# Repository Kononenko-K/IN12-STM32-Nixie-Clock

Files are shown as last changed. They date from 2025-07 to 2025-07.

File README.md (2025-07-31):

# IN12-STM32-Nixie-Clock

STM32 Nixie clock project with four Soviet IN-12 indicators.

<br/>
<p align="center">
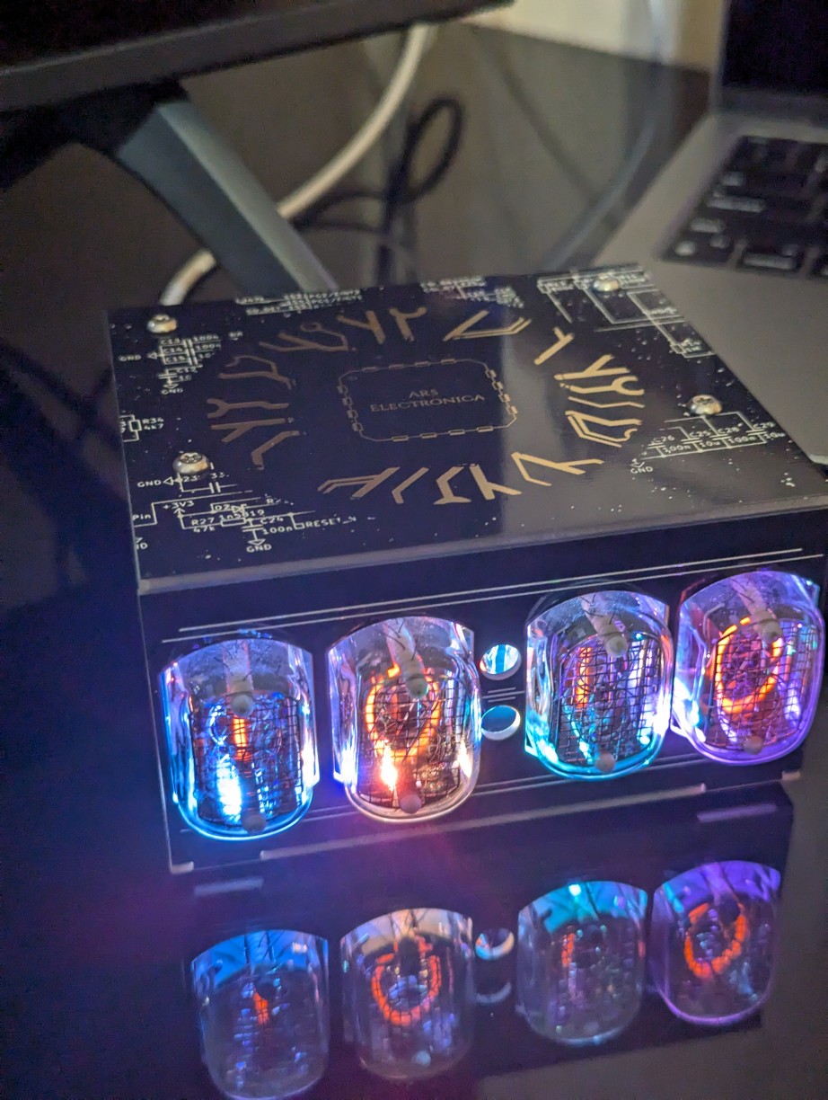
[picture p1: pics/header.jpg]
    
</p>

## Overview

<br/>
<p align="center">
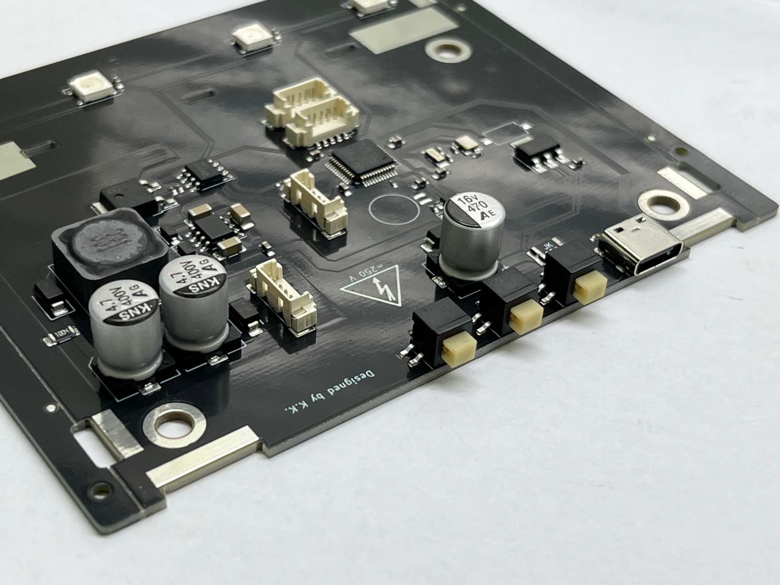
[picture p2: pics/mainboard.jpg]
    
</p>

This project provides a complete solution for building an STM32-powered 
Nixie clock with Soviet IN-12 tubes. It operates on a 5V power supply 
via a Type-C connector and features an internal high voltage generator.

## Hardware

<br/>
<p align="center">
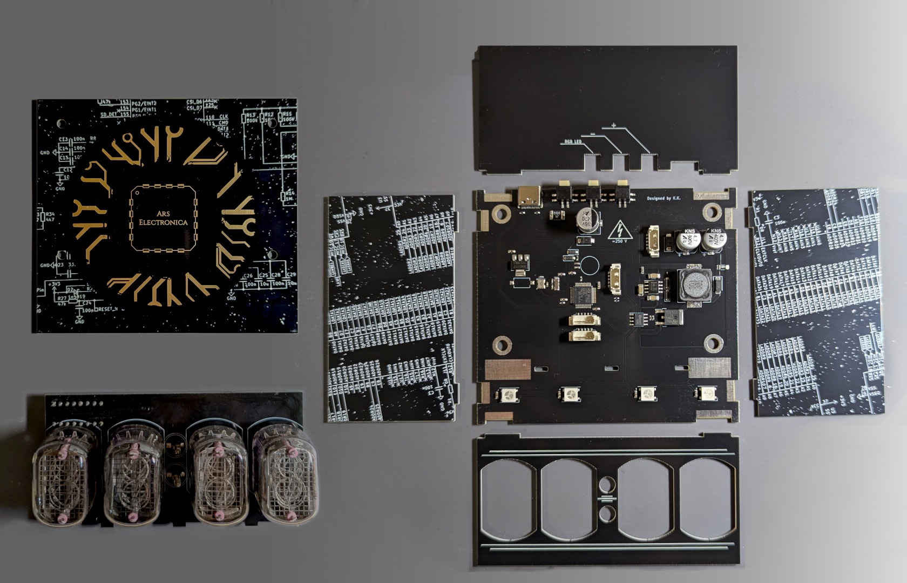
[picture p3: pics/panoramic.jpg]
    
</p>

### [**Display Module**](/Hardware/nixie%20display/project.pdf)
- Utilizes the K155ID1 (equivalent to SN74141N) as a high-voltage 
BCD-to-decimal decoder.
- Drives four Nixie tubes using dynamic scanning with TLP627 optocouplers.

### [**Controller Module**](/Hardware/mcu%20board/project.pdf)
- Based on the STM32F103C8Tx microcontroller, featuring:
  - Internal RTC peripheral for timekeeping;
  - Battery input for maintaining time during power off;
  - Boost converter for high-voltage generation using a PWM signal from 
one of the MCU's timers;
  - Four WS2812B addressable RGB LEDs for tube illumination.

### **Connection Guide**

| **Display Module** | **Controller Module** |
|---|---|
| A1 | PA4 |
| A2 | PA6 |
| A3 | PB0 |
| A4 | PB2 |
|--------------------|-----------------------|
| D0 | PA5 |
| D1 | PB1 |
| D2 | PB10 |
| D3 | PA7 |
|--------------------|-----------------------|
| NE | PA10 |
|--------------------|-----------------------|
| +180V | HV |
|--------------------|-----------------------|
| +5V | +5V |

Connect all respective GNDs together.

## Firmware

The firmware is developed as a Makefile project, generated with 
STM32CubeMX. It can be built using:

```sh
make clean && make
```

To upload the firmware, use ST-LINK/V2 and OpenOCD with the following 
command:

```sh
openocd -f interface/stlink.cfg \
          -f target/stm32f1x.cfg \
          -c "init; reset halt; flash write_image erase ./build/new_nixie.bin 0x08000000; reset halt; exit"
```

The code implements firmware protection and it can be removed with:
```sh
openocd -f interface/stlink.cfg \
          -f target/stm32f1x.cfg \
          -c "init; reset halt; stm32f1x unlock 0; reset halt; exit"
```

For convenience, you can use the provided scripts:
- [flash.sh](/Firmware/flash.sh)
- [remove_protection.sh](/Firmware/remove_protection.sh)

The boost converter's duty cycle may require adjustment based on component 
type. Additionally, delay settings can be fine-tuned for optimal tube 
switching. The firmware includes a feature to prevent cathode poisoning by 
cycling through all tubes every 5 minutes. Also, there are 15 different modes 
of illumination using addressable LEDs.

## License

- The **Firmware** in this project is licensed under the 
[MIT License](/Firmware/LICENSE), with the exception of portions of the 
firmware code that are copyrighted by STMicroelectronics; such portions are 
subject to the original licensing terms provided by STMicroelectronics.
- The **Hardware** in this project is licensed under the 
[CERN Open Hardware Licence Permissive (CERN OHL-P)](/Hardware/LICENSE).

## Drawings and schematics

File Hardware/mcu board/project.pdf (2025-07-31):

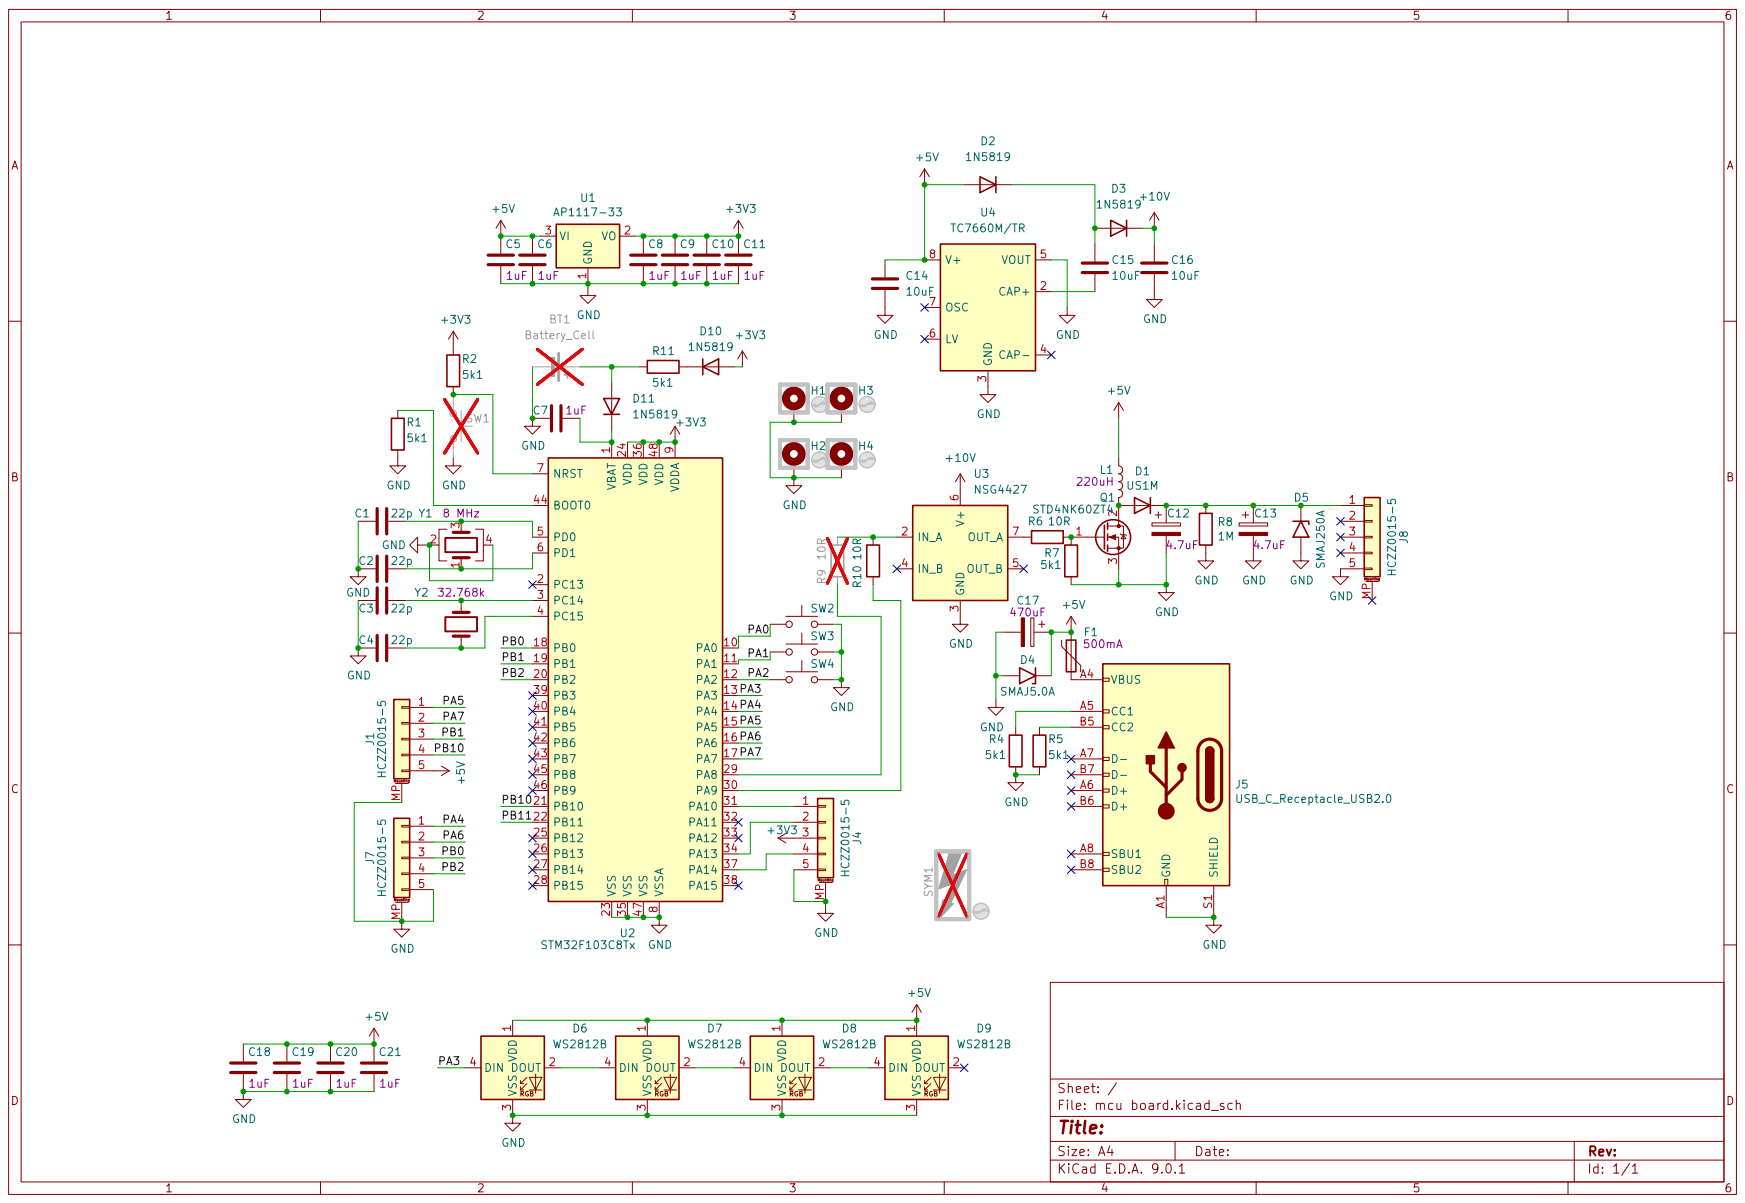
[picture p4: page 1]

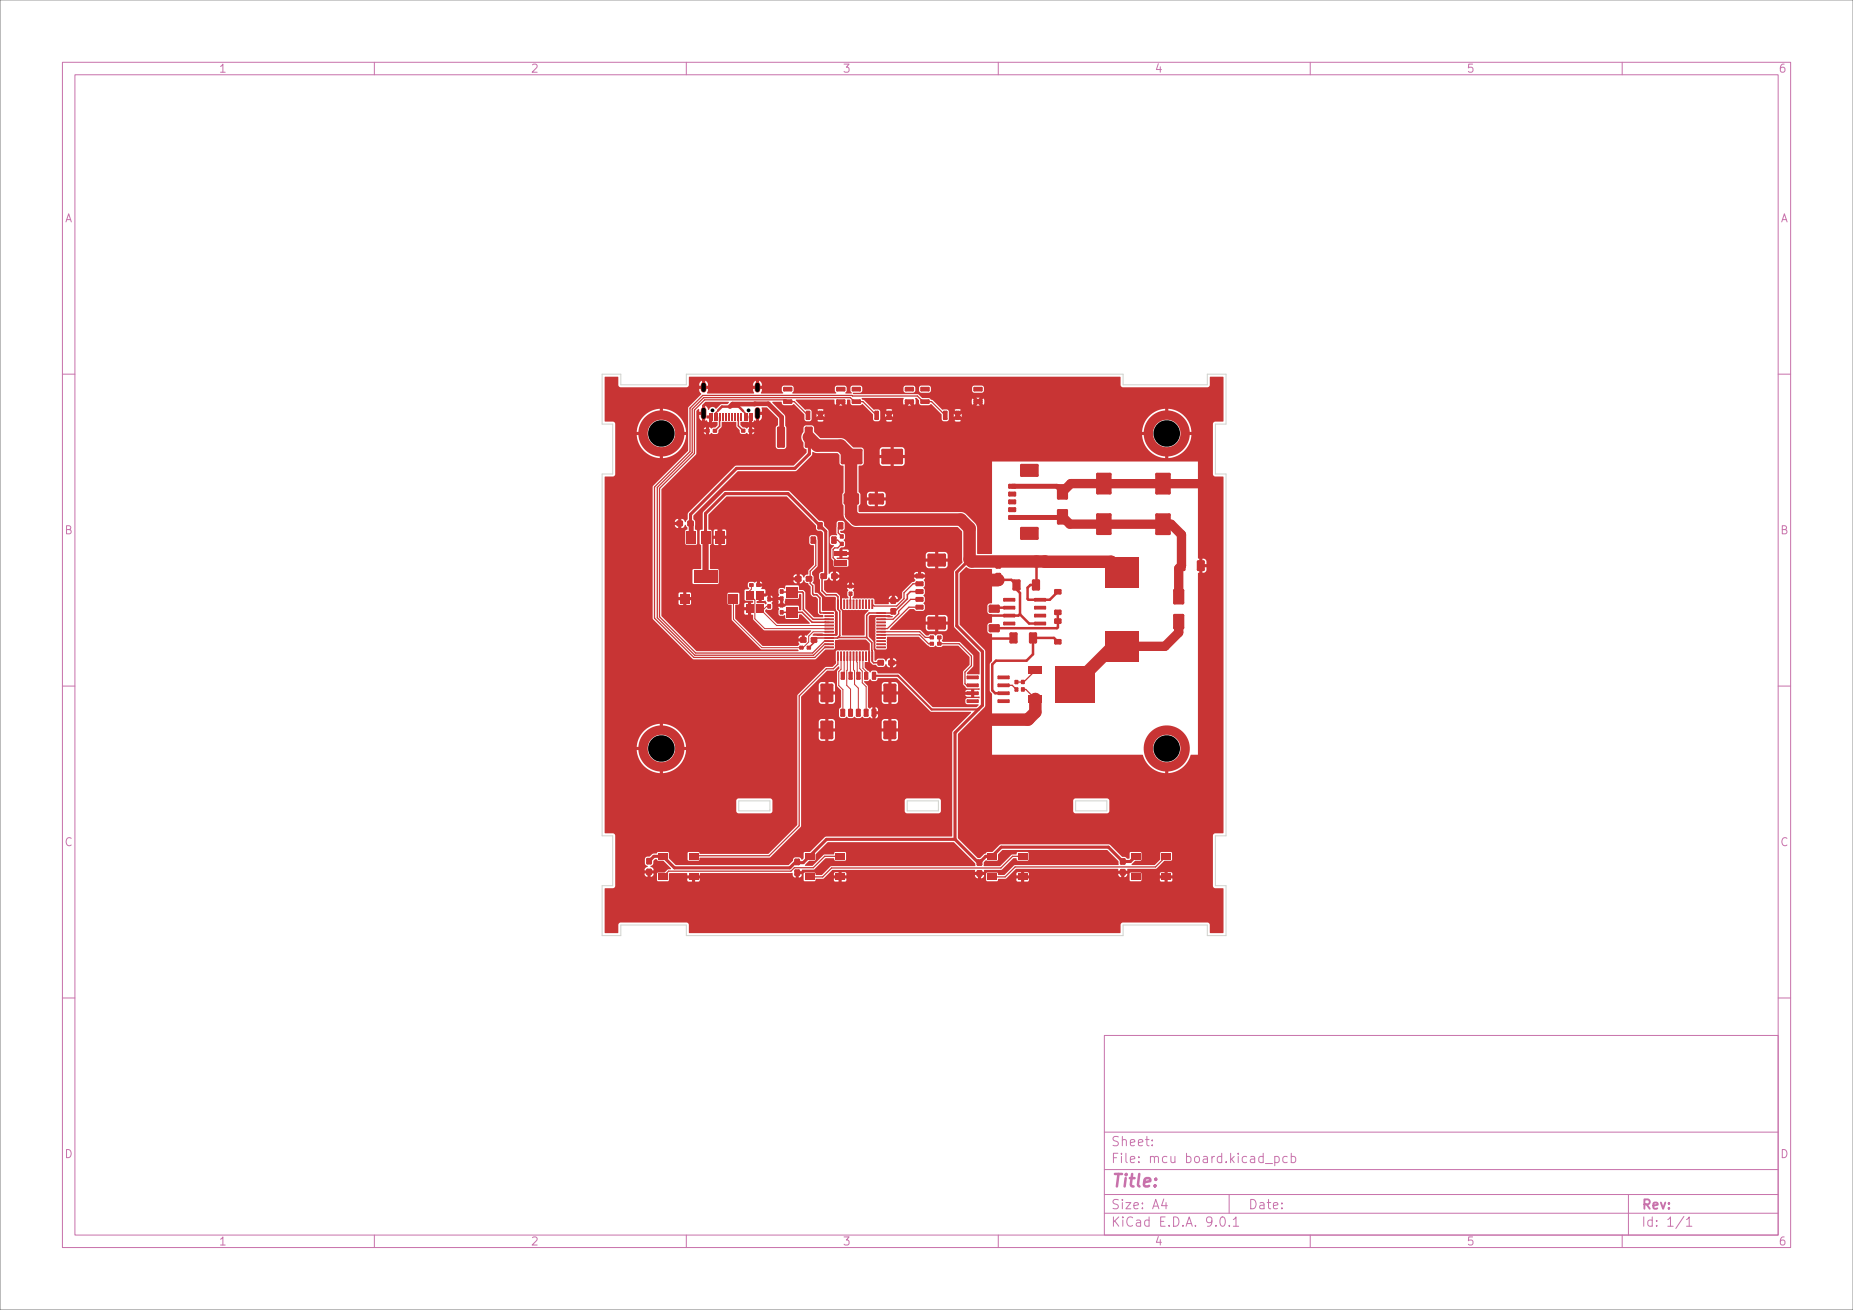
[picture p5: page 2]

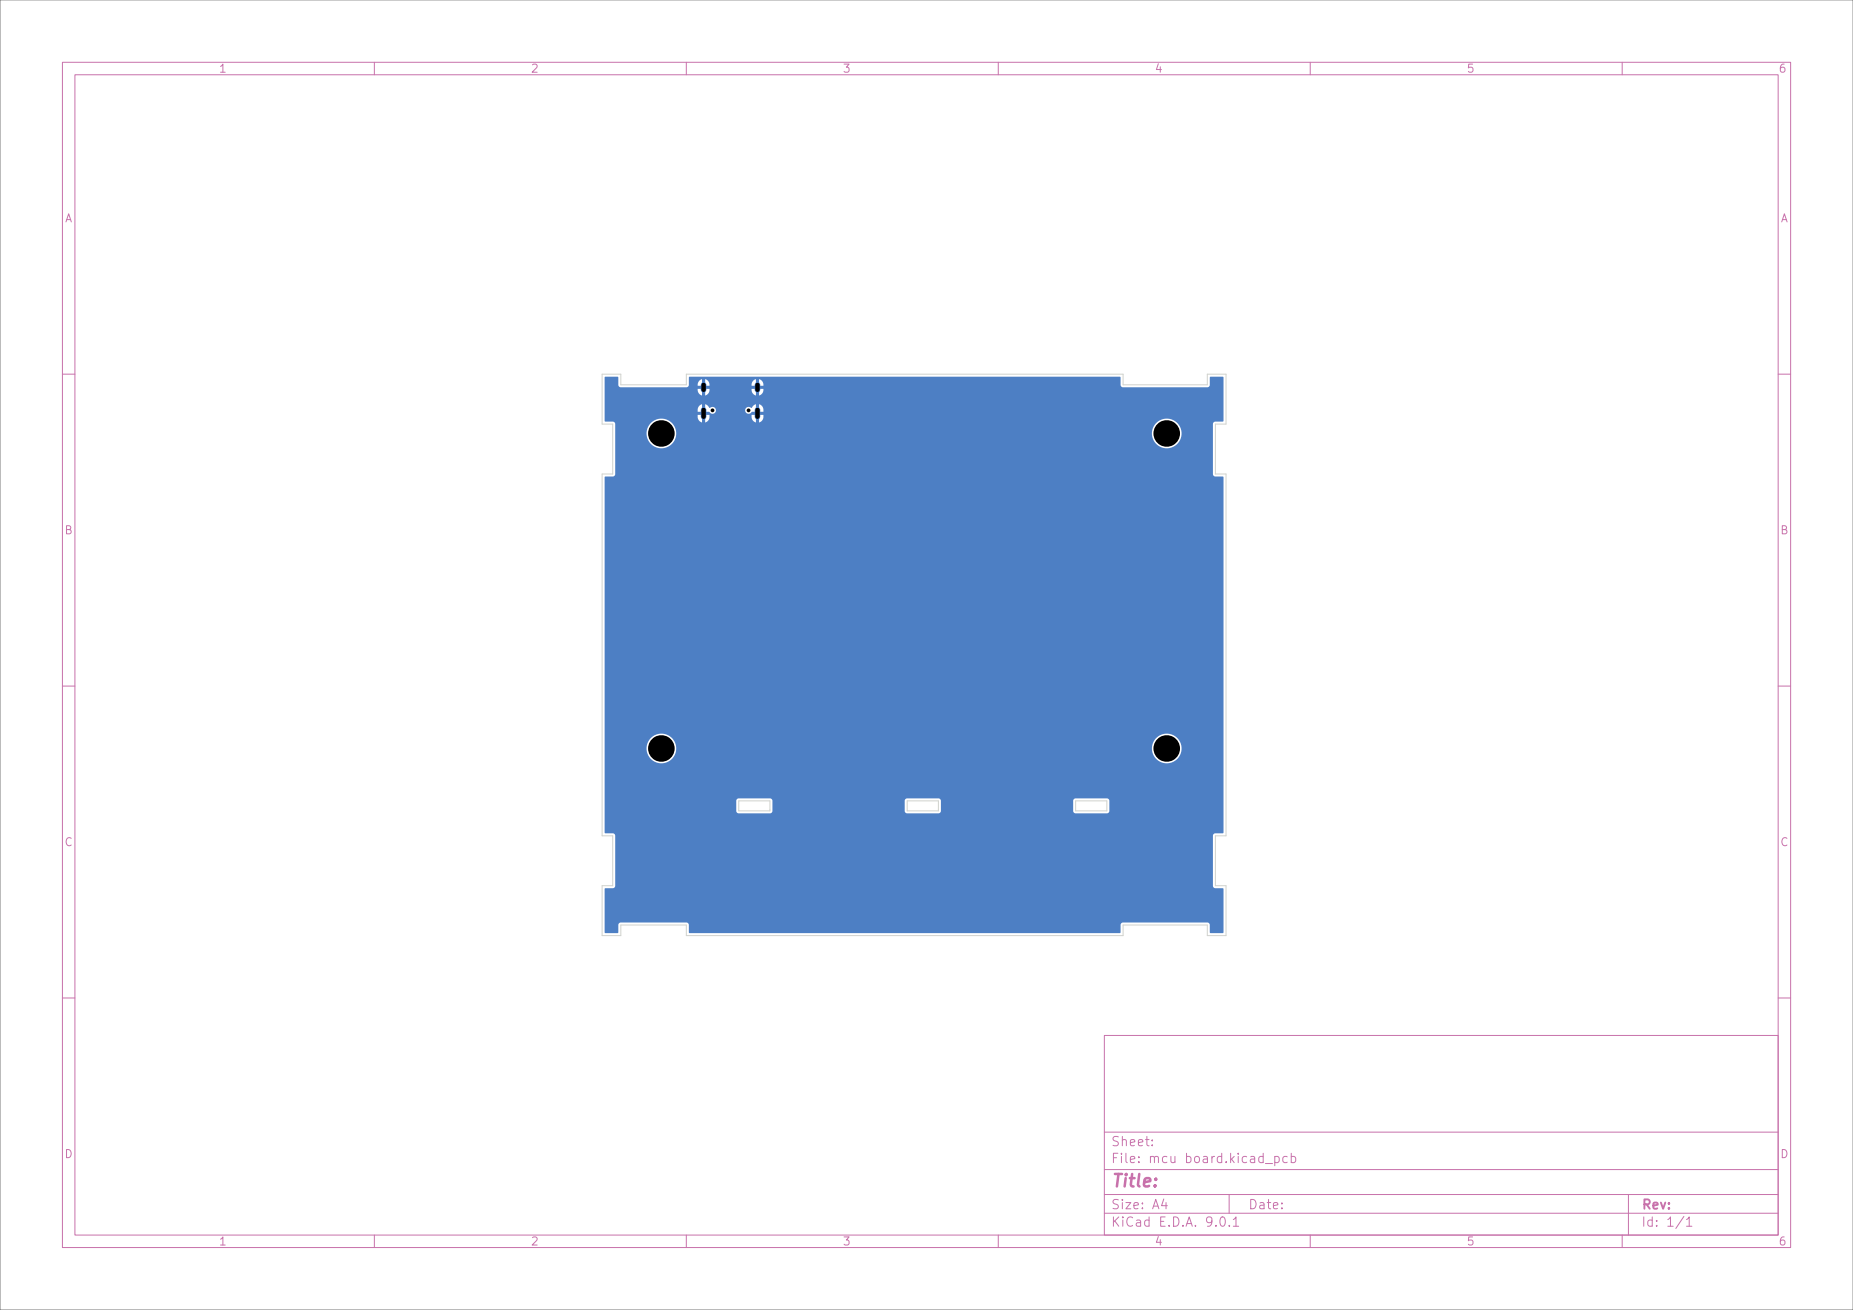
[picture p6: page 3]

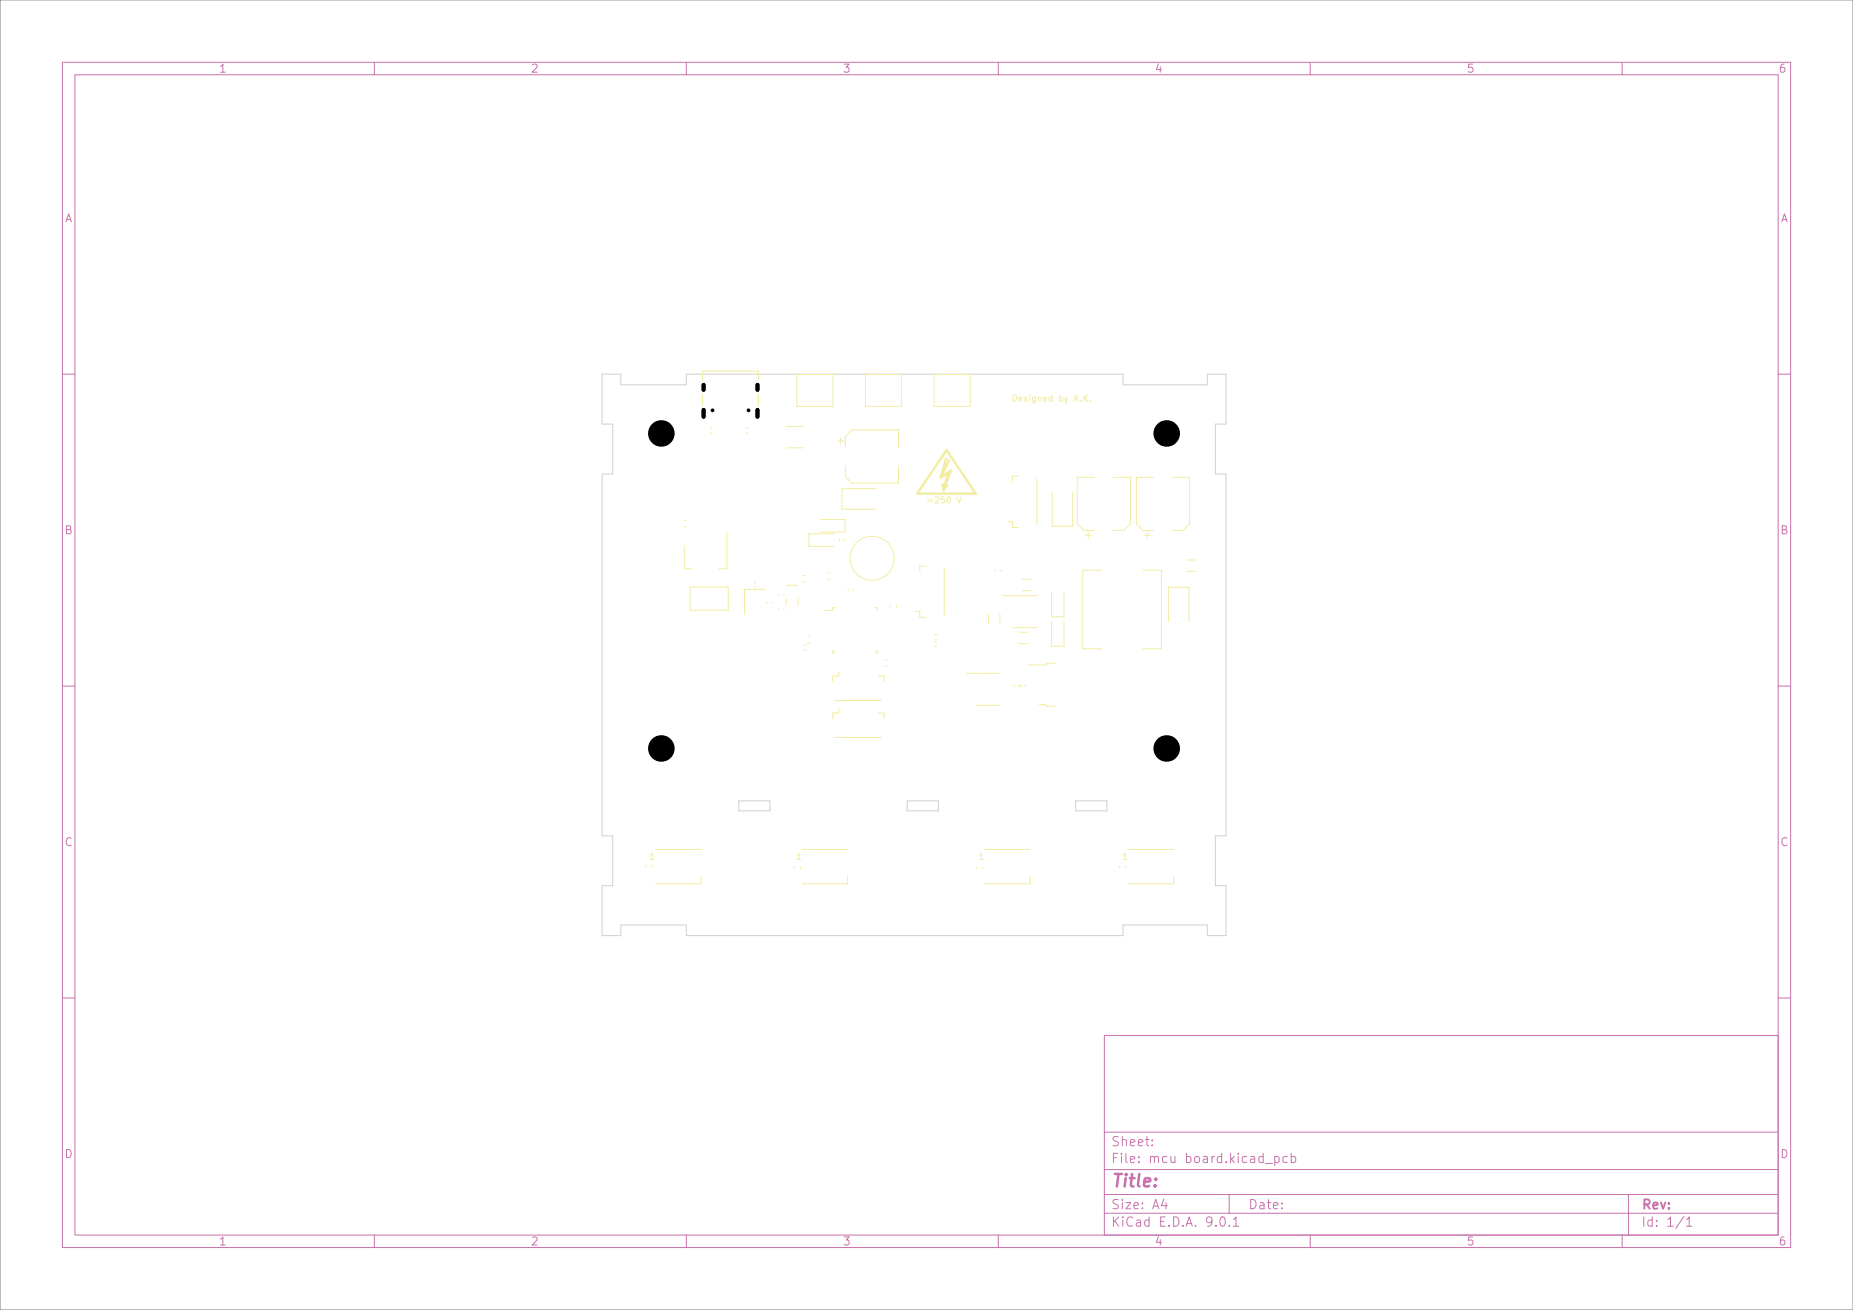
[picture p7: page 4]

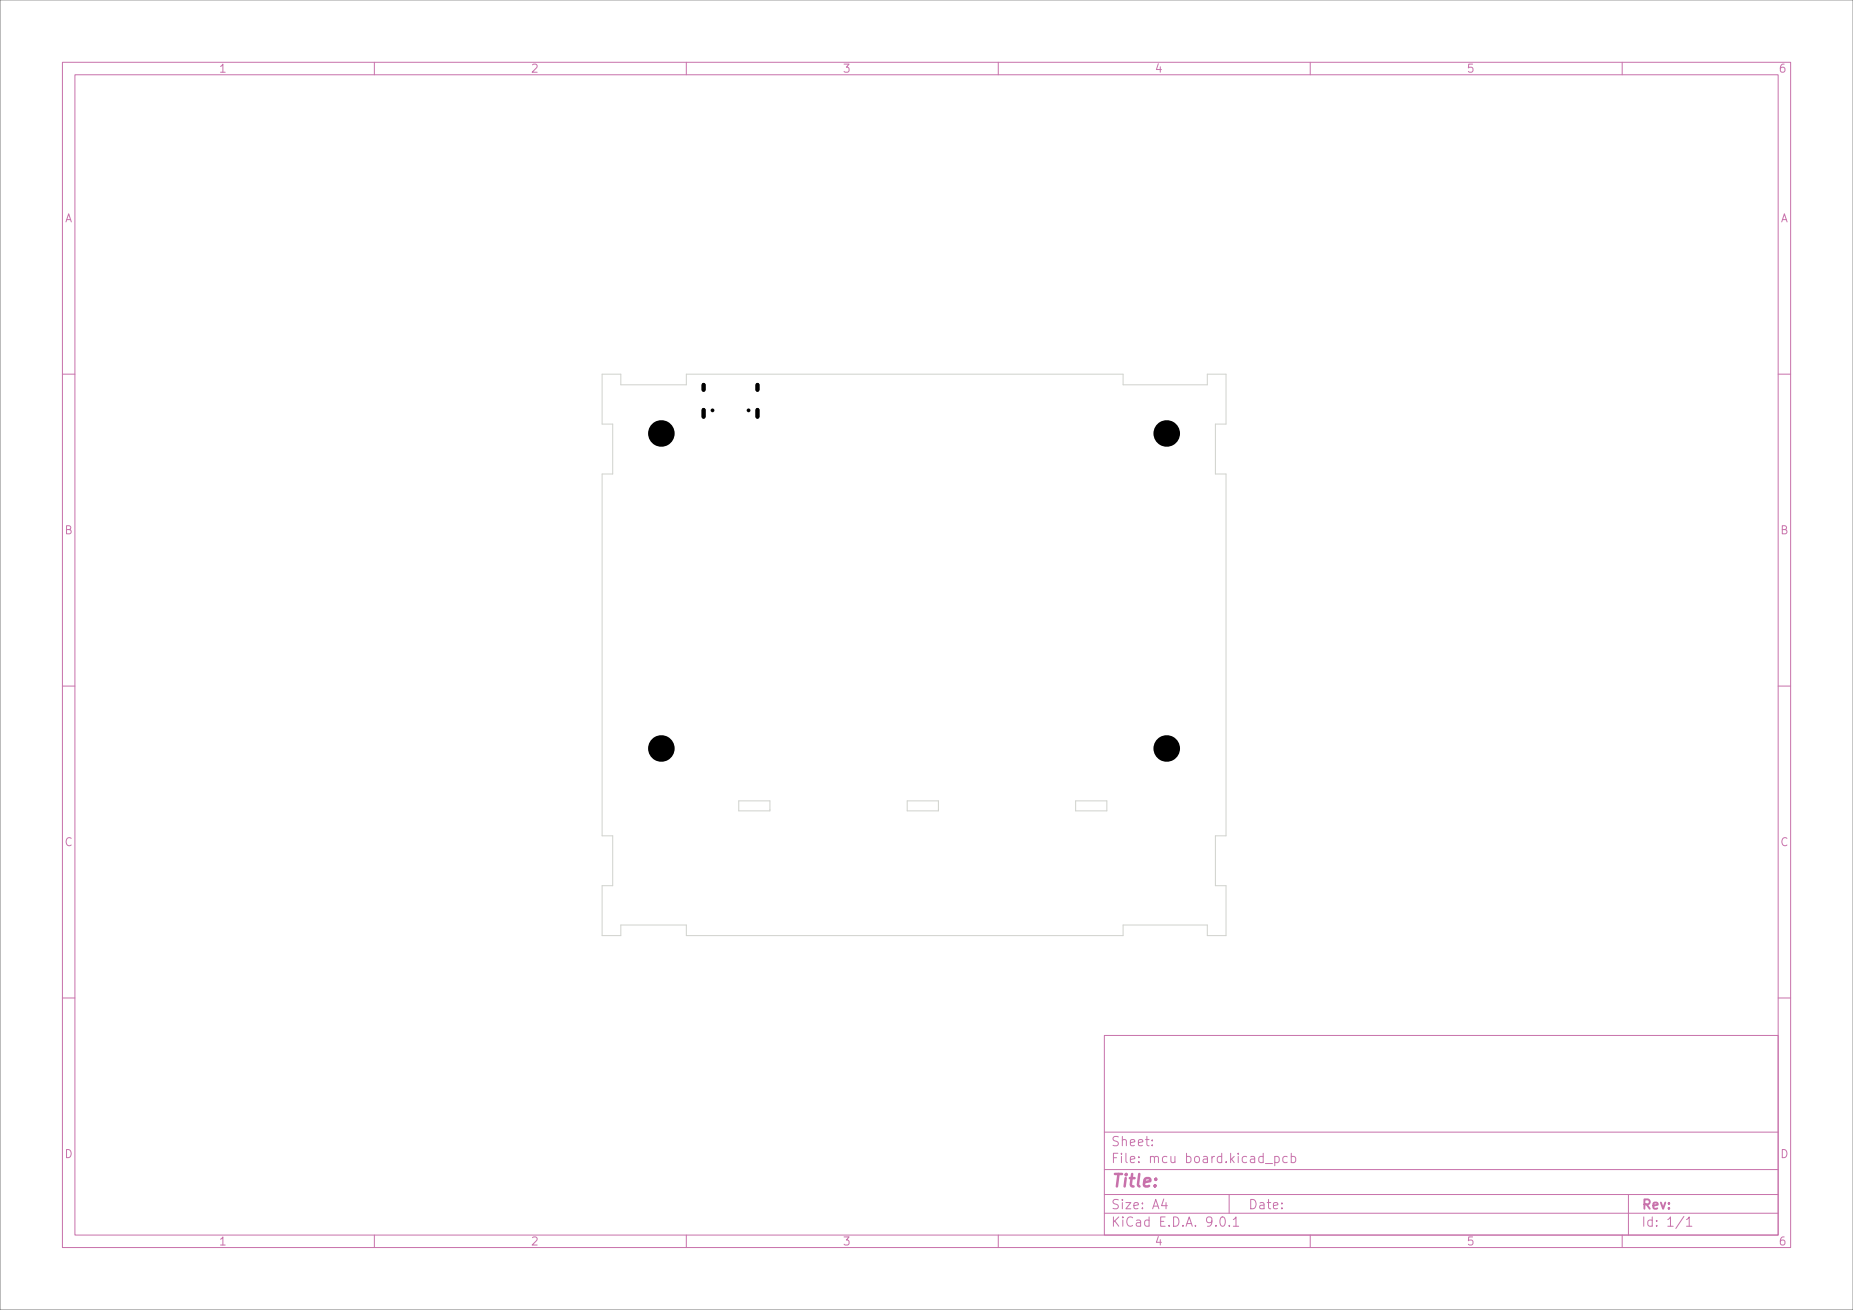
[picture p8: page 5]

Reference | Qty | DNP | Part Number | Manufacturer
C1,C2,C3,C4 | 4 | | CC0402JRNPO9BN180 | YAGEO
C5,C6,C7,C8,C9,C10,C11,C18,C19,C20,C21 | 11 | | CC0603KRX5R8BB105 | YAGEO
C12,C13 | 2 | | 189RV165 | KNSCHA
C14,C15,C16 | 3 | | CC1206KKX5R8BB106 | YAGEO
C17 | 1 | | GVE1C477M0810CNVC | HRK
D1 | 1 | | US1M | JSMSEMI
D2,D3,D10,D11 | 4 | | 1N5819HW-7-F | Diodes Incorporated
D4 | 1 | | SMAJ5.0A | FUXINSEMI
D5 | 1 | | SMAJ250A | DOWO
D6,D7,D8,D9 | 4 | | XL-5050RGBC-WS2812B | XINGLIGHT
F1 | 1 | | JK-MSMD050-30 | Jinrui Electronic Materials Co.
J1,J4,J7,J8 | 4 | | HCZZ0015-5 | Hong Cheng
J5 | 1 | | TYPE-C-31-M-12 | Korean Hroparts Elec
L1 | 1 | | SHOU HAN CYH125-330UH | SHOU HAN CYH125-330UH
Q1 | 1 | | STD4NK60ZT4 | STMicroelectronics
R1,R2,R4,R5,R7,R11 | 6 | | RC0402FR-075K1L | YAGEO
R6,R10 | 2 | | RC0402FR-0710RL | YAGEO
R8 | 1 | | RC1206FR-071ML | YAGEO
SW2,SW3,SW4 | 3 | | XKB5858-W-F-75 | XKB Connection
U1 | 1 | | AMS1117-3.3 | UMW(Youtai Semiconductor Co., Ltd.)
U2 | 1 | | STM32F103C8T6 | STMicroelectronics
U3 | 1 | | NSG4427 | WXNSIC
U4 | 1 | | TC7660M/TR | HGSEMI
Y1 | 1 | | TAXM8M4RFDCET2T | Yajingxin
Y2 | 1 | | XKXGI-SUA-32.768K | YXC Crystal Oscillators

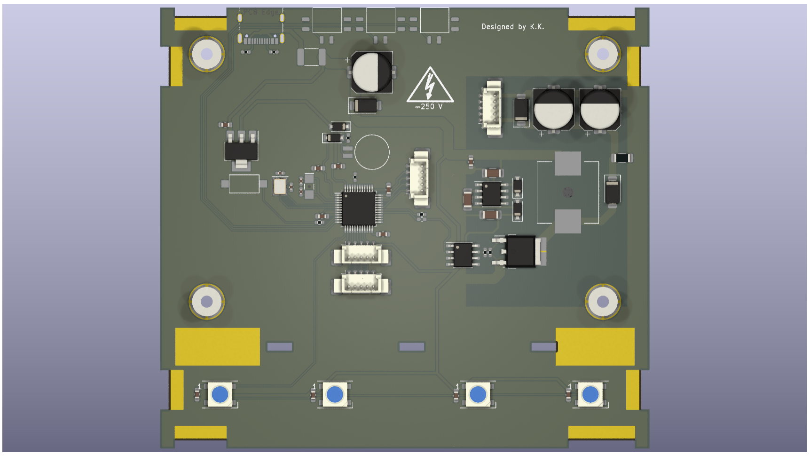
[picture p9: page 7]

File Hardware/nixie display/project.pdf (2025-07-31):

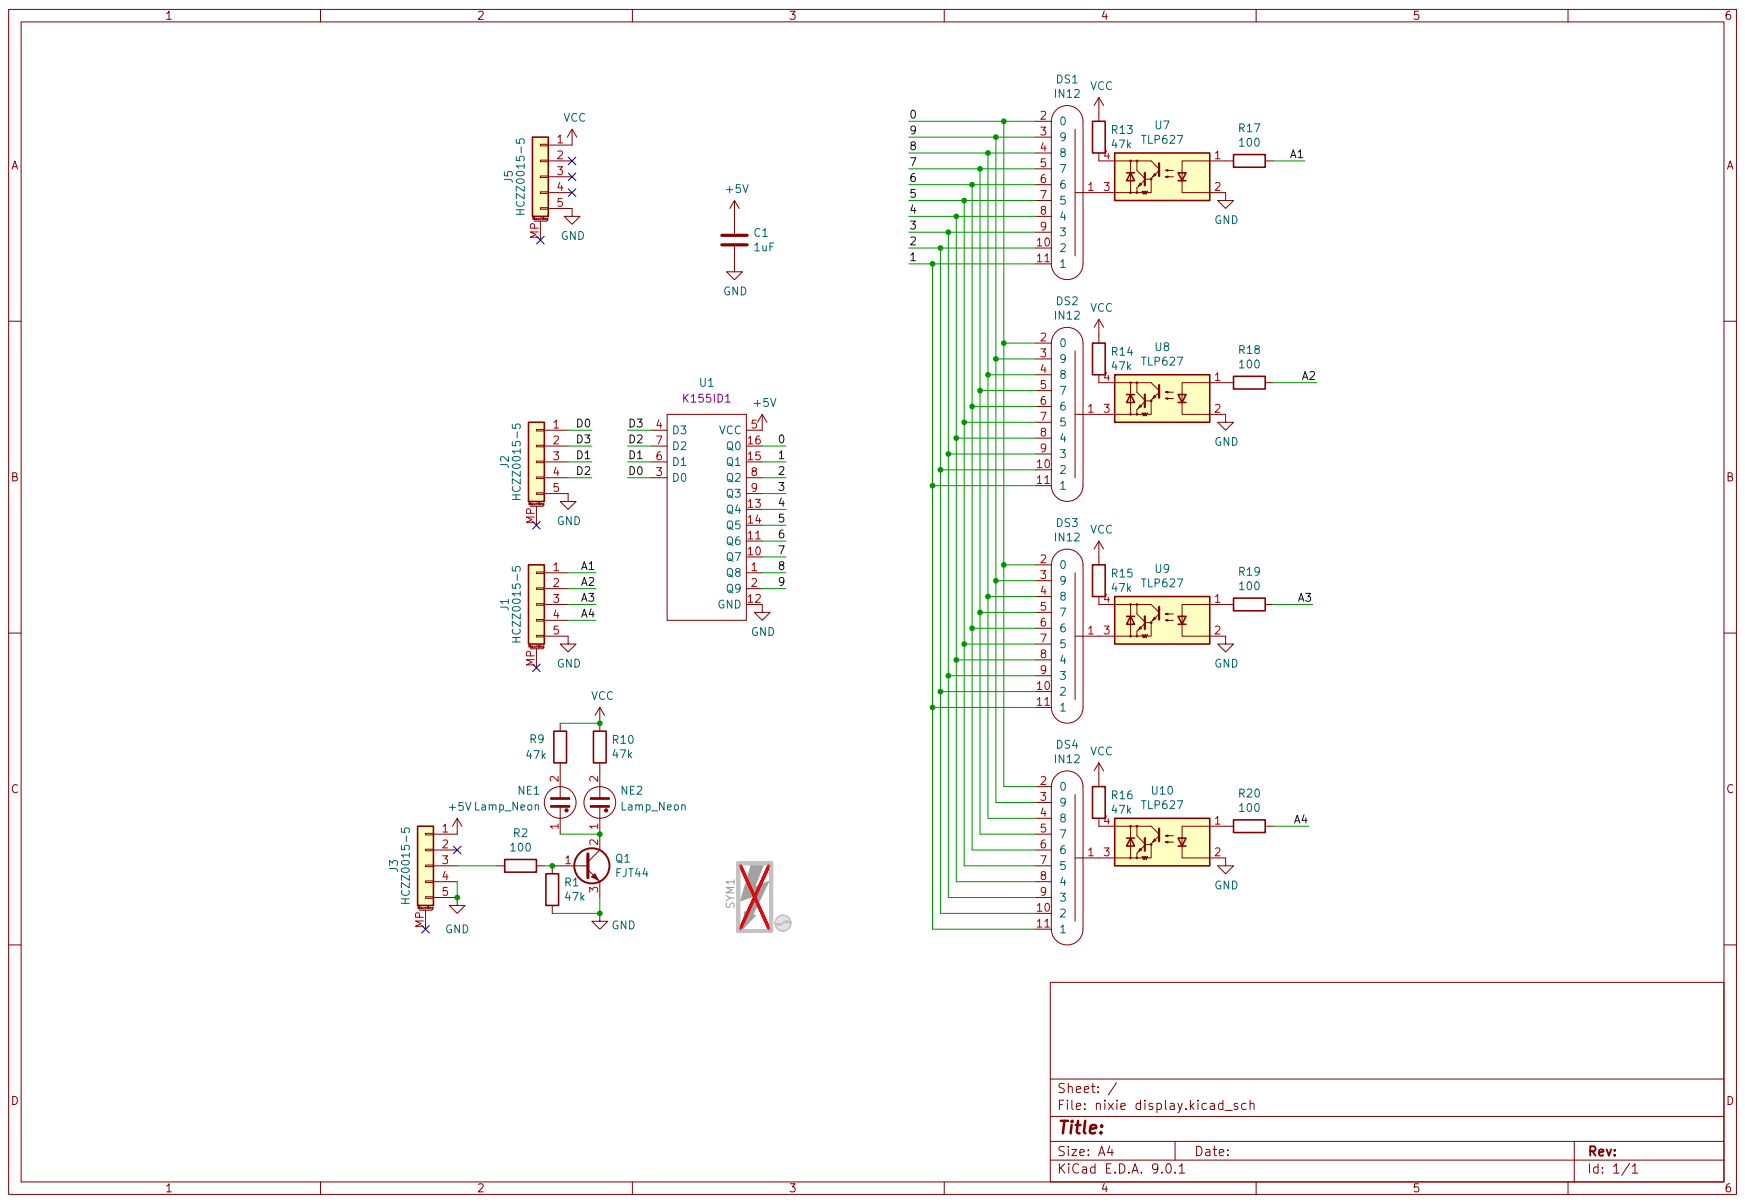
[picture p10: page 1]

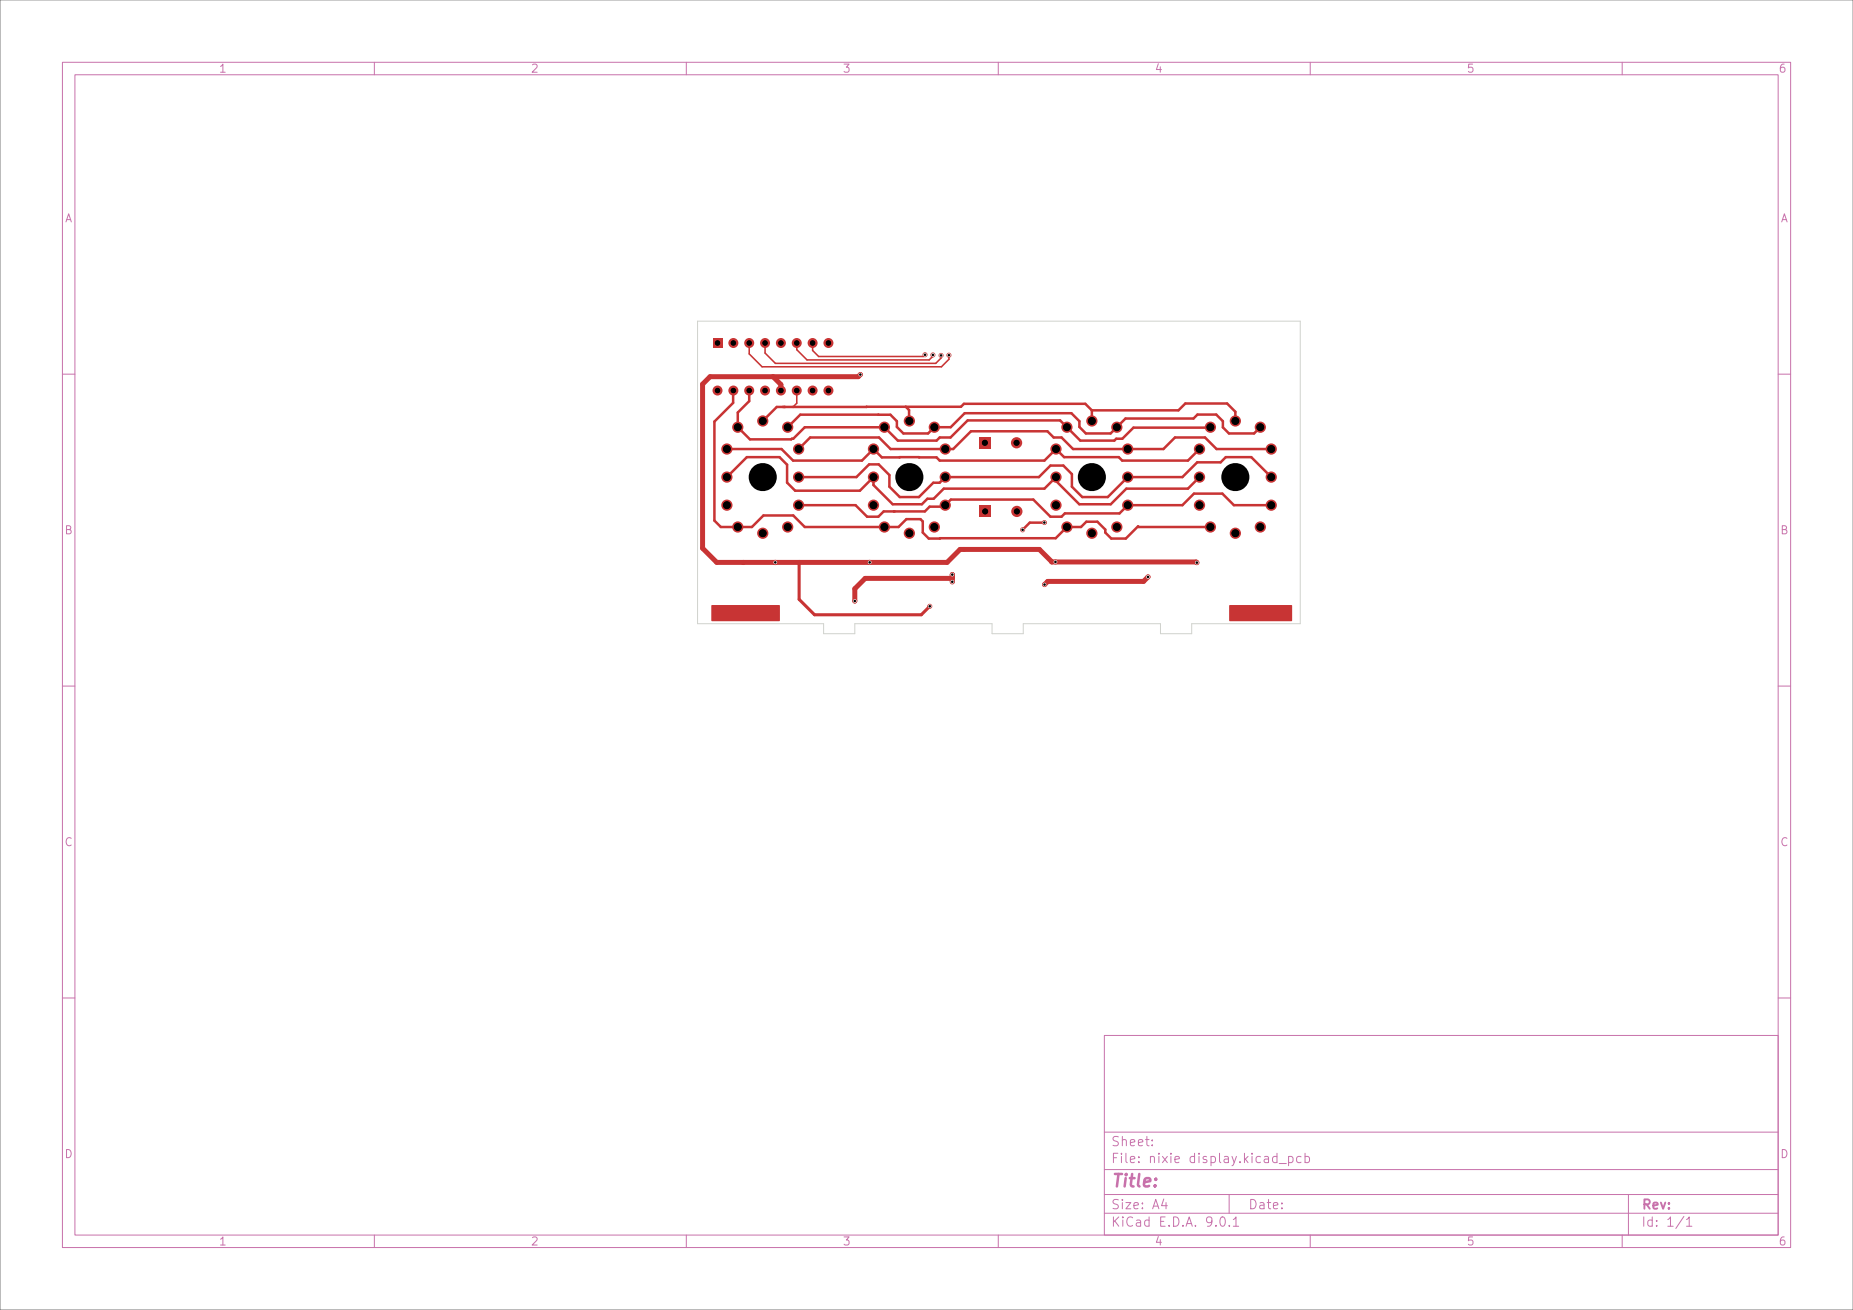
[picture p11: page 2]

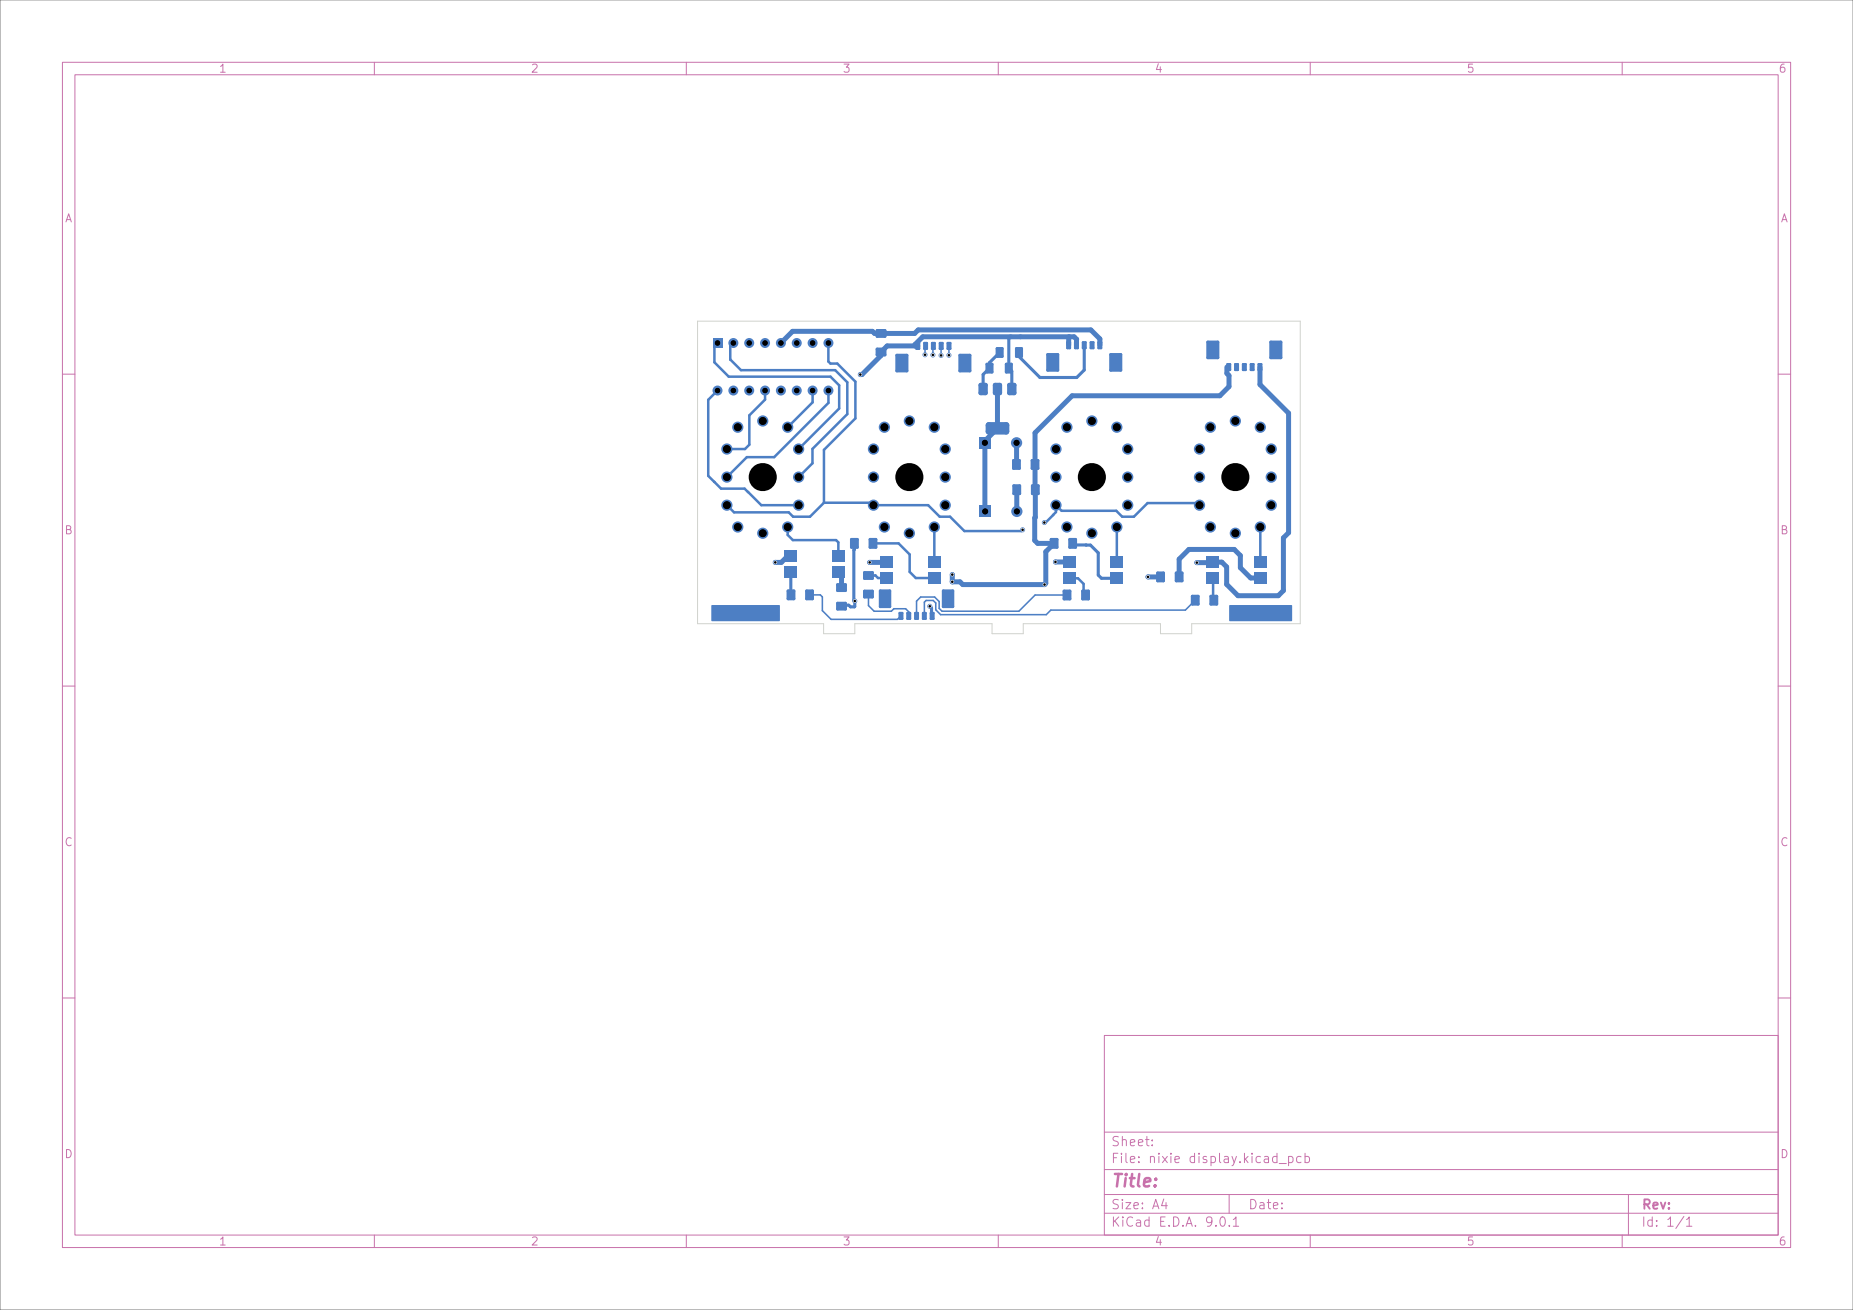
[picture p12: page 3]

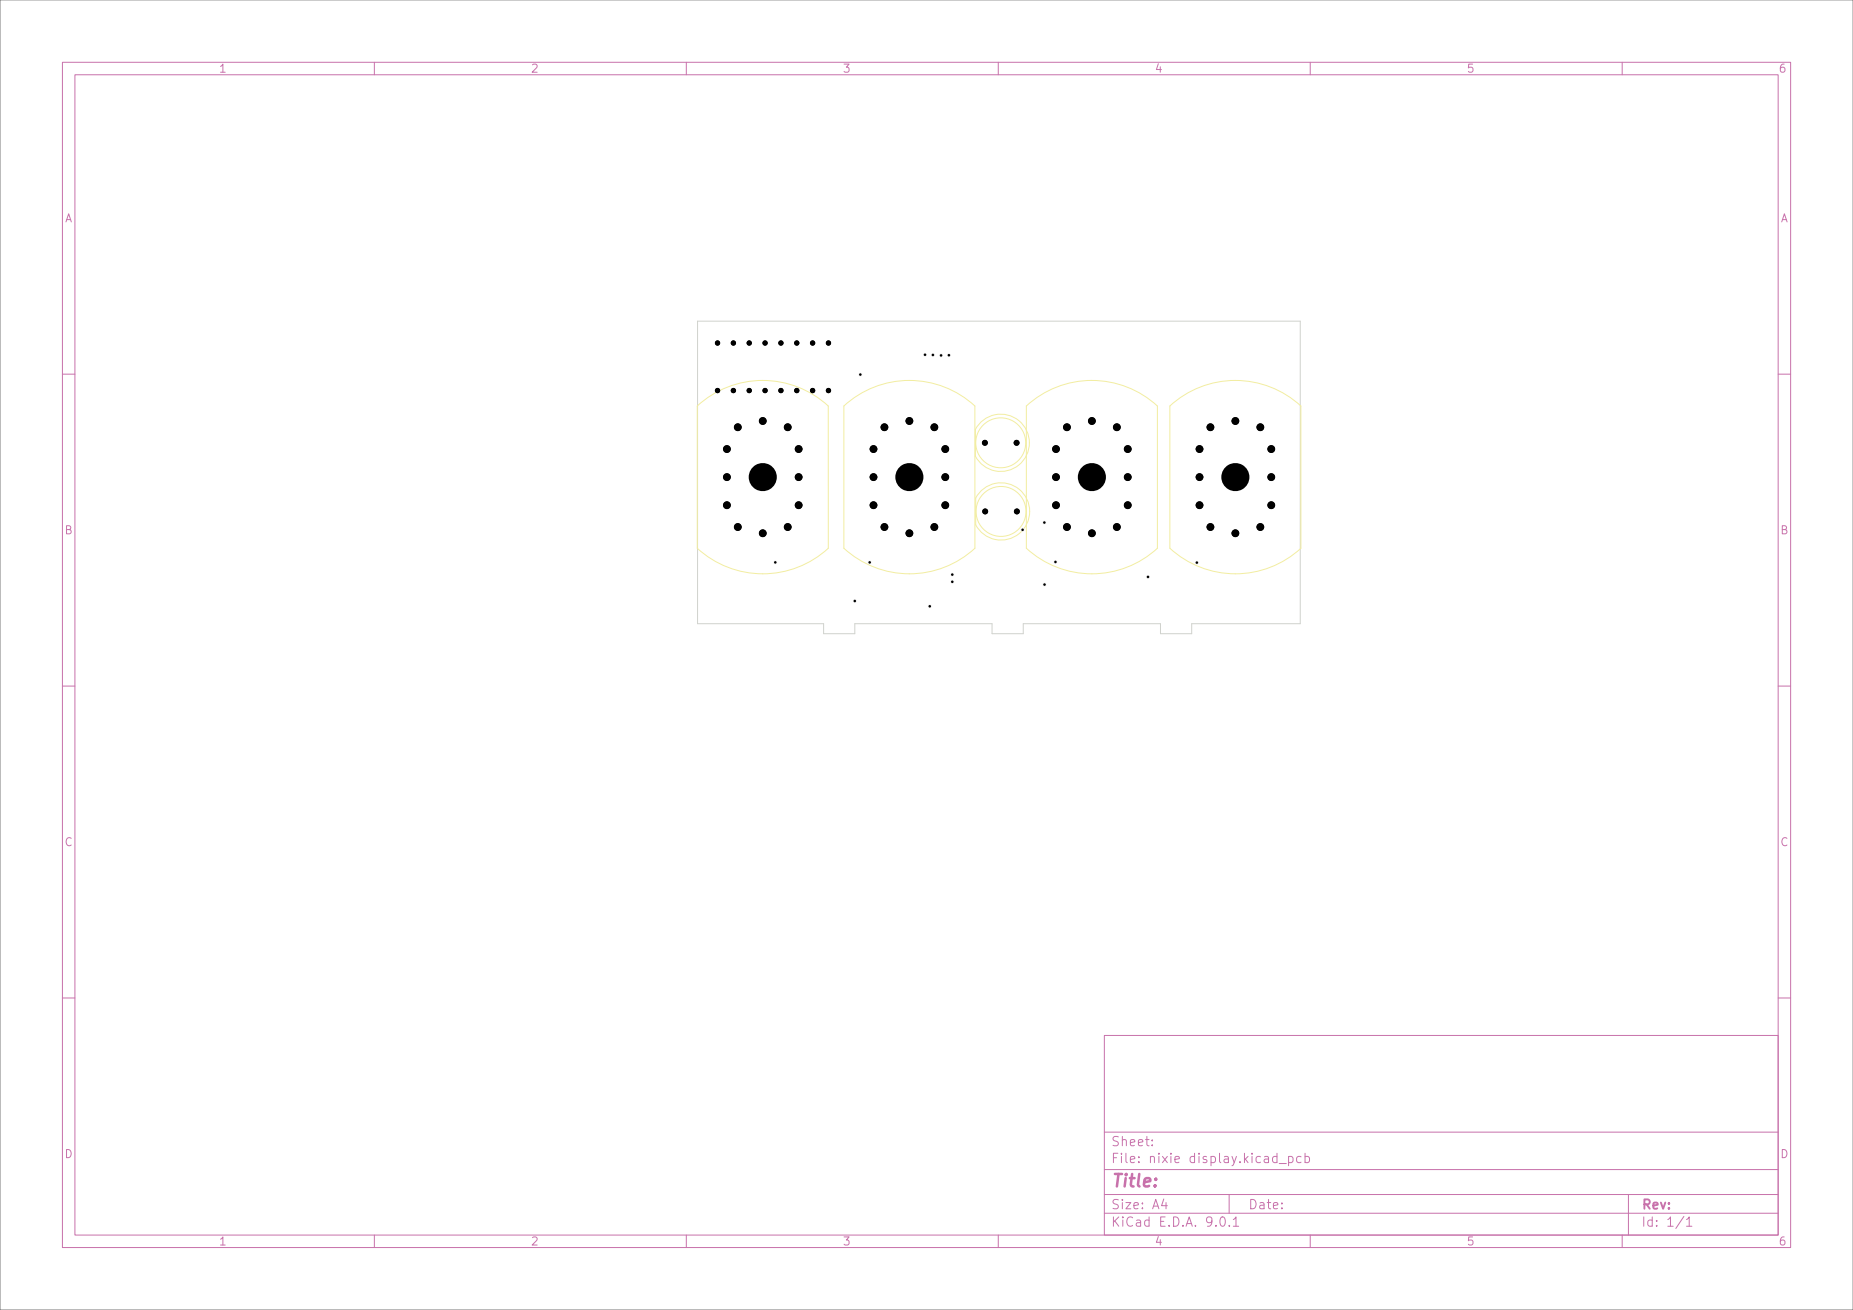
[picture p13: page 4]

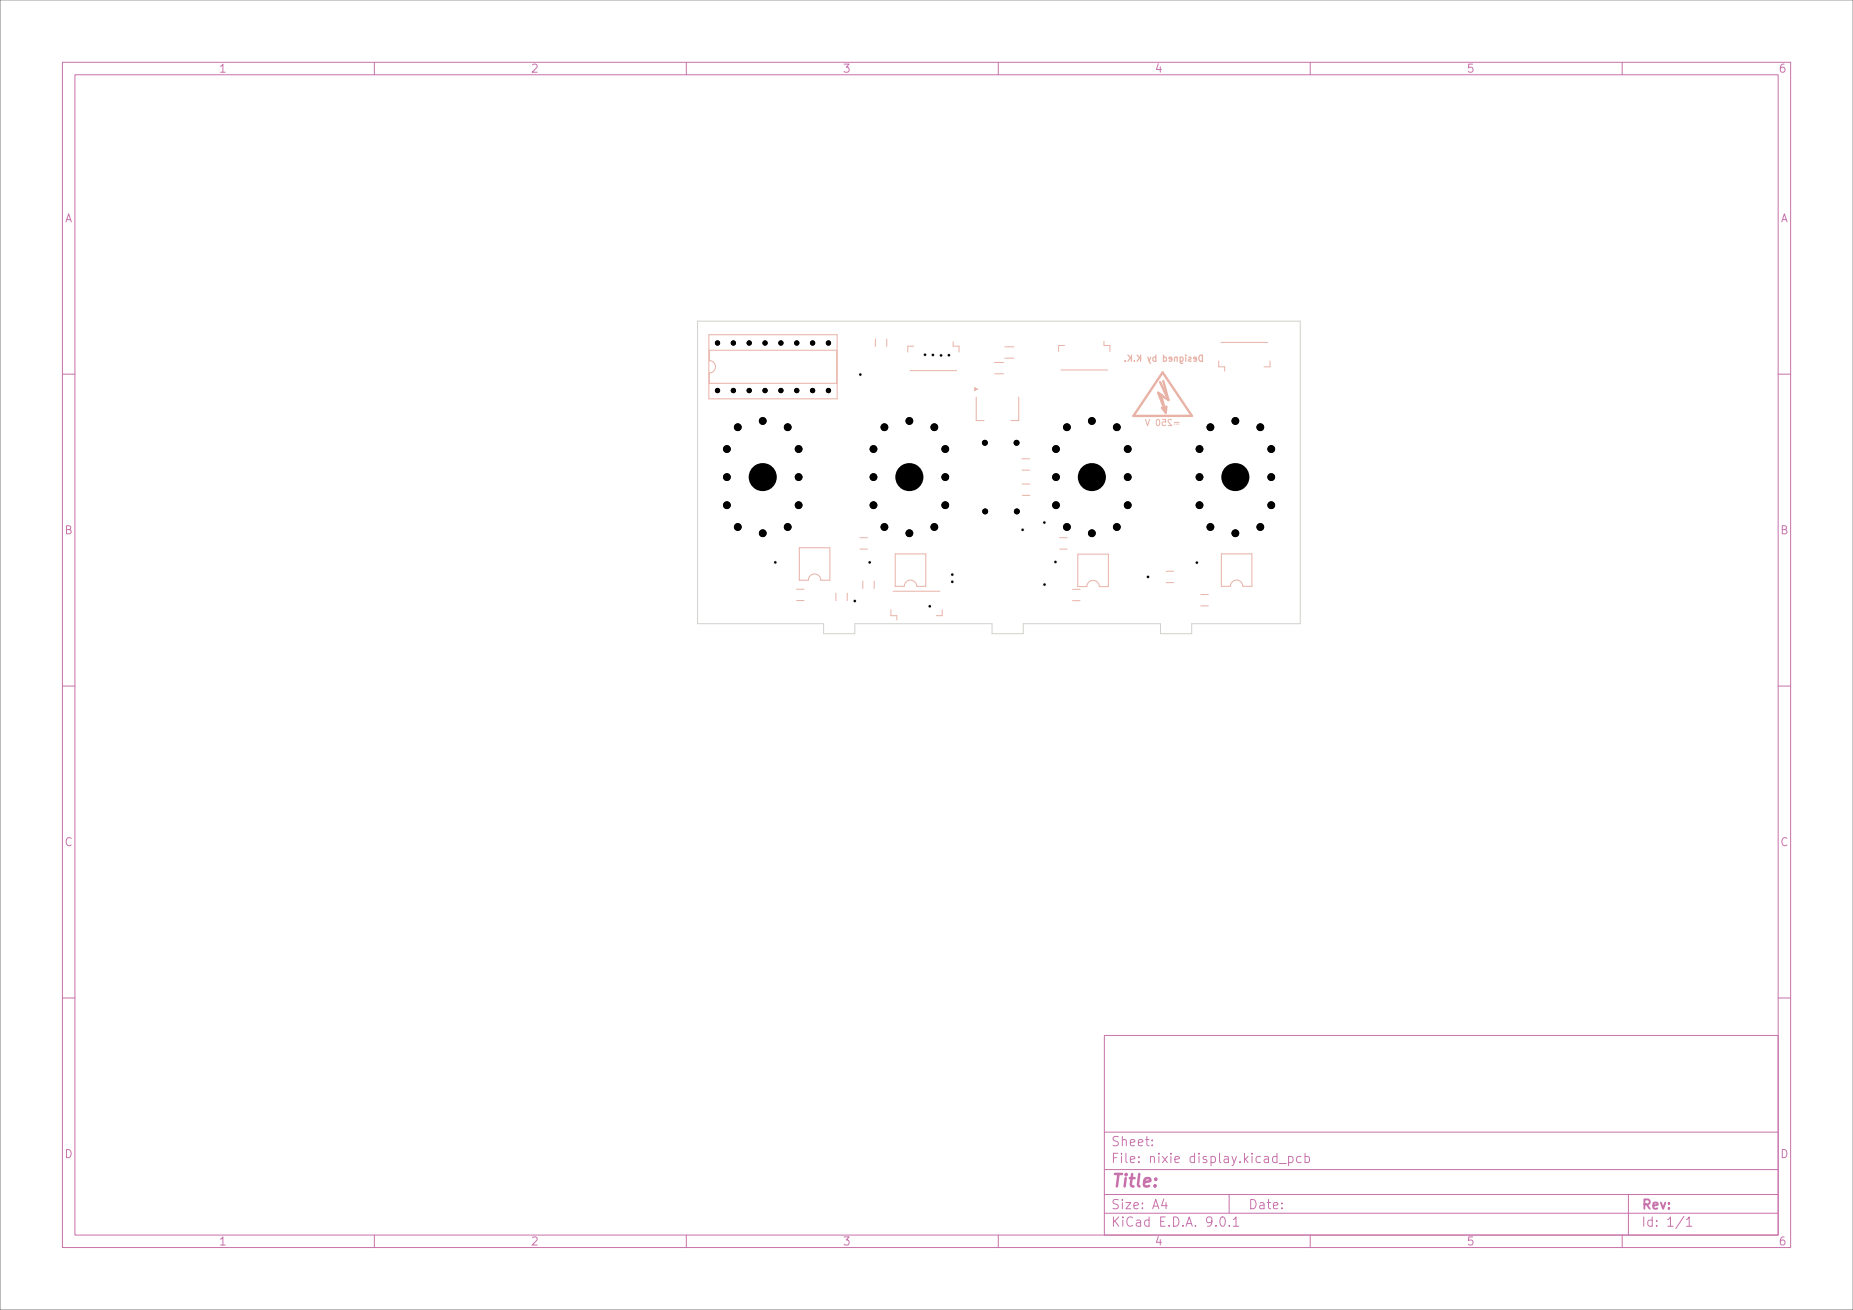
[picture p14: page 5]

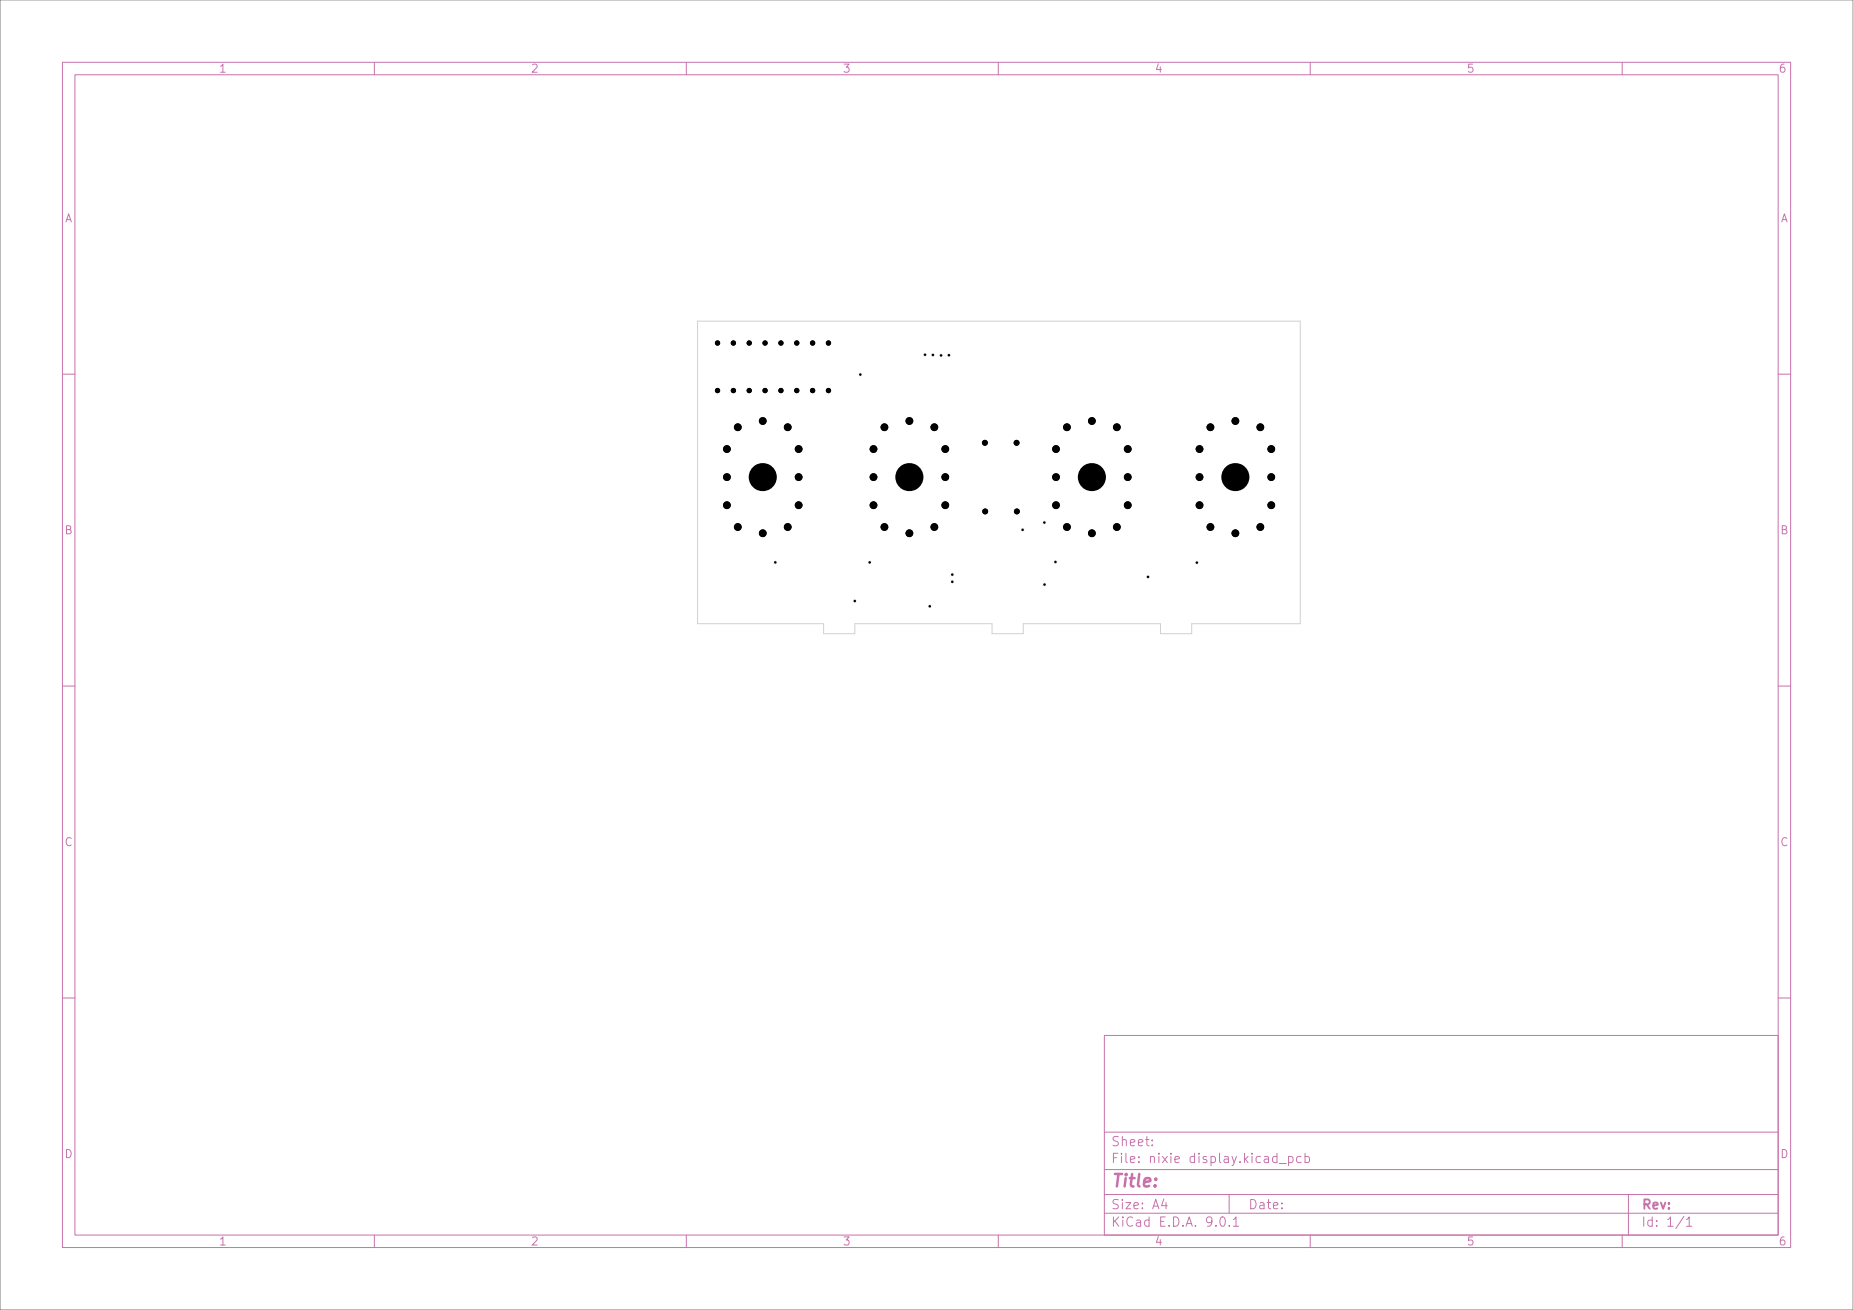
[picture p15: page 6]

nixie display

Reference | Value | Qty | DNP | Part Number | Manufacturer
C1 | 1uF | 1 | CC1206KKX7R9BB105 | YAGEO
DS1,DS2,DS3,DS4 | IN12 | 4 | IN12
J1,J2,J3,J5 | HCZZ0015-5 | 4 | HCZZ0015-5 | Hong Cheng
NE1,NE2 | Lamp_Neon | 2 | NE-2
Q1 | FJT44 | 1 | FJT44 | WEIDA
R1,R9,R10,R13,R14,R15,R16 | 47k | 7 | RC1206JR-0747KL | YAGEO
R2,R17,R18,R19,R20 | 100 | 5 | RC1206JR-07100RL | YAGEO
U1 | DS1009-16AT1NX-0A2 | 1 | DS1009-16AT1NX-0A2 | CONNFLY Elec
U7,U8,U9,U10 | TLP627 | 4 | TLP627(TP1,F) | TOSHIBA


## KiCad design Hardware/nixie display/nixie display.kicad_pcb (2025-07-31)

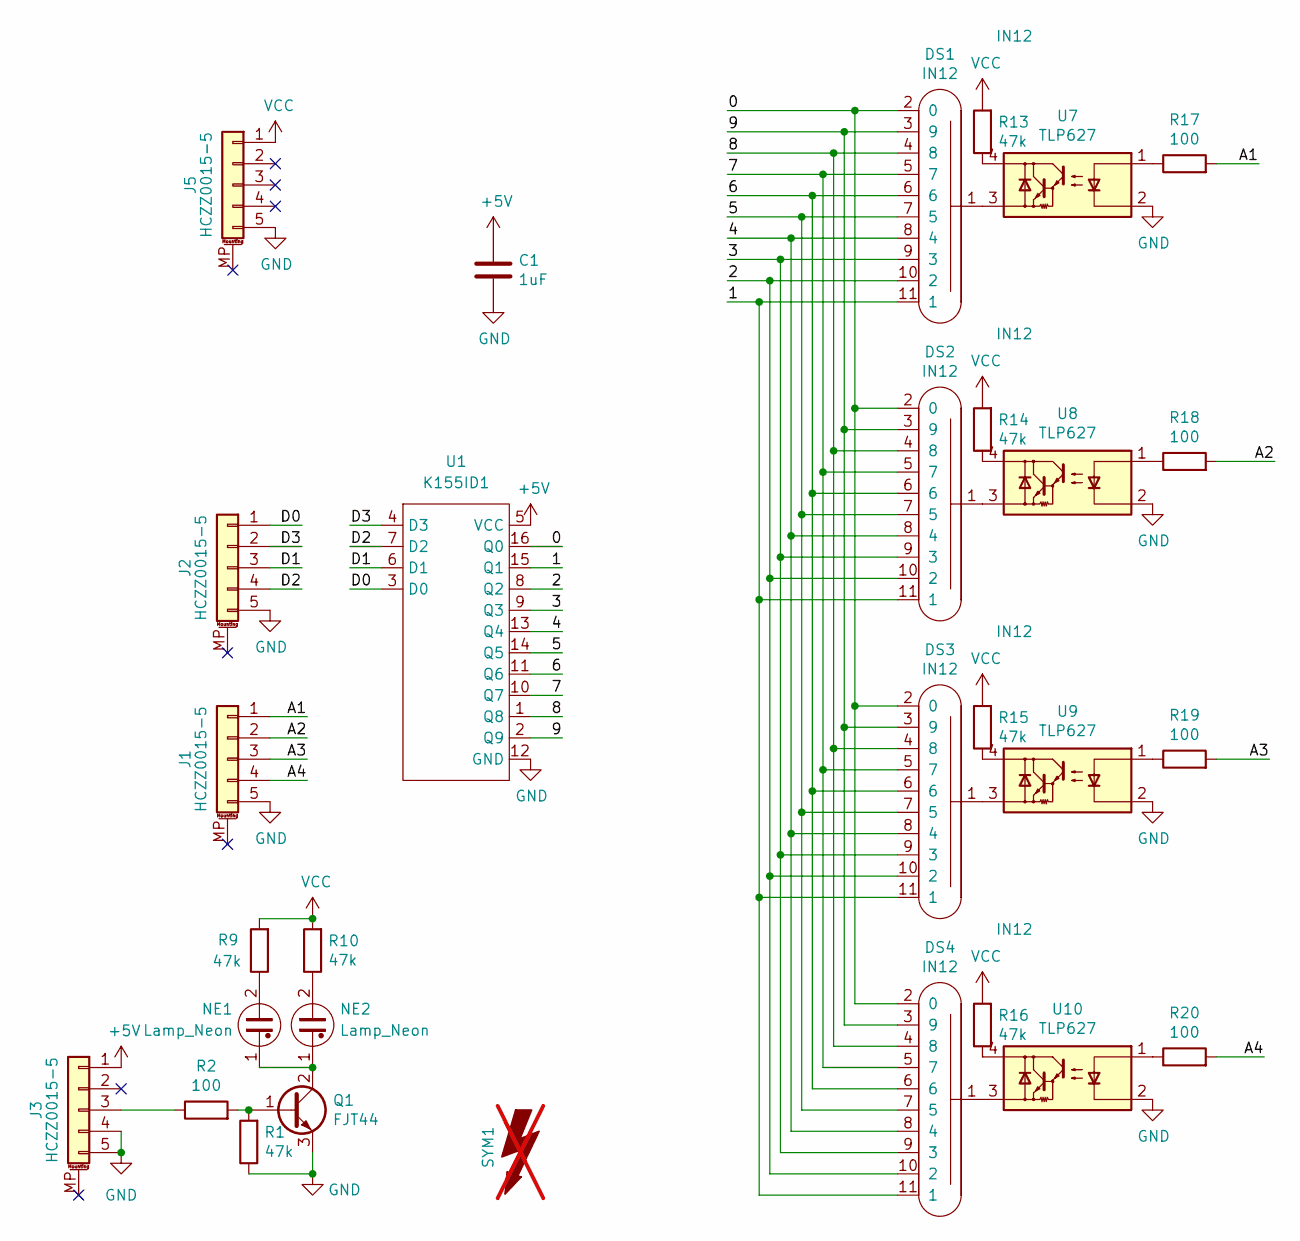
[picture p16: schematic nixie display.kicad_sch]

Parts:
C1: 1uF; C_1206_3216Metric_Pad1.42x1.75mm_HandSolder; Part Number CC1206KKX7R9BB105
DS1, DS2, DS3, DS4: IN12; in12; Part Number IN12
J1, J2, J3, J5: HCZZ0015-5; Molex_PicoBlade_53398-0571_1x05-1MP_P1.25mm_Vertical; Part Number HCZZ0015-5
NE1, NE2: Lamp_Neon; neon; Part Number NE-2
Q1: FJT44; SOT-223-3_TabPin2; Part Number FJT44
R1: 47k; R_1206_3216Metric_Pad1.30x1.75mm_HandSolder; Part Number RC1206JR-0747KL
R2: 100; R_1206_3216Metric_Pad1.30x1.75mm_HandSolder; Part Number RC1206JR-07100RL
R9, R10, R13, R14, R15, R16: 47k; R_1206_3216Metric_Pad1.42x1.75mm_HandSolder; Part Number RC1206JR-0747KL
R17, R18, R19, R20: 100; R_1206_3216Metric_Pad1.42x1.75mm_HandSolder; Part Number RC1206JR-07100RL
SYM1: SYM_Flash_Large; HighVoltage; not fitted
U1: DS1009-16AT1NX-0A2; DIP-16_W7.62mm_Socket; Part Number DS1009-16AT1NX-0A2
U7, U8, U9, U10: TLP627; SMDIP-4_W7.62mm; Part Number TLP627(TP1,F)

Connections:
+5V: C1.1, J3.1, U1.5 (VCC)
/0: DS1.2 (0), DS2.2 (0), DS3.2 (0), DS4.2 (0), U1.16 (Q0)
/1: DS1.11 (1), DS2.11 (1), DS3.11 (1), DS4.11 (1), U1.15 (Q1)
/2: DS1.10 (2), DS2.10 (2), DS3.10 (2), DS4.10 (2), U1.8 (Q2)
/3: DS1.9 (3), DS2.9 (3), DS3.9 (3), DS4.9 (3), U1.9 (Q3)
/4: DS1.8 (4), DS2.8 (4), DS3.8 (4), DS4.8 (4), U1.13 (Q4)
/5: DS1.7 (5), DS2.7 (5), DS3.7 (5), DS4.7 (5), U1.14 (Q5)
/6: DS1.6, DS2.6, DS3.6, DS4.6, U1.11 (Q6)
/7: DS1.5 (7), DS2.5 (7), DS3.5 (7), DS4.5 (7), U1.10 (Q7)
/8: DS1.4 (8), DS2.4 (8), DS3.4 (8), DS4.4 (8), U1.1 (Q8)
/9: DS1.3 (9), DS2.3 (9), DS3.3 (9), DS4.3 (9), U1.2 (Q9)
/A1: J1.1, R17.2
/A2: J1.2, R18.2
/A3: J1.3, R19.2
/A4: J1.4, R20.2
/D0: J2.1, U1.3 (D0)
/D1: J2.3, U1.6 (D1)
/D2: J2.4, U1.7 (D2)
/D3: J2.2, U1.4 (D3)
GND: C1.2, J1.5, J2.5, J3.4, J3.5, J5.5, Q1.3 (E), R1.1, U1.12 (GND), U7.2, U8.2, U9.2, U10.2
unnamed: DS1.1, U7.3
unnamed: DS2.1, U8.3
unnamed: DS3.1, U9.3
unnamed: DS4.1, U10.3
unnamed: J3.3, R2.1
unnamed: NE1.2, R9.1
unnamed: NE2.2, R10.1
unnamed: Q1.1 (B), R1.2, R2.2
unnamed: NE1.1, NE2.1, Q1.2 (C)
unnamed: R13.1, U7.4
unnamed: R14.1, U8.4
unnamed: R15.1, U9.4
unnamed: R16.1, U10.4
unnamed: R17.1, U7.1
unnamed: R18.1, U8.1
unnamed: R19.1, U9.1
unnamed: R20.1, U10.1
VCC: J5.1, R9.2, R10.2, R13.2, R14.2, R15.2, R16.2

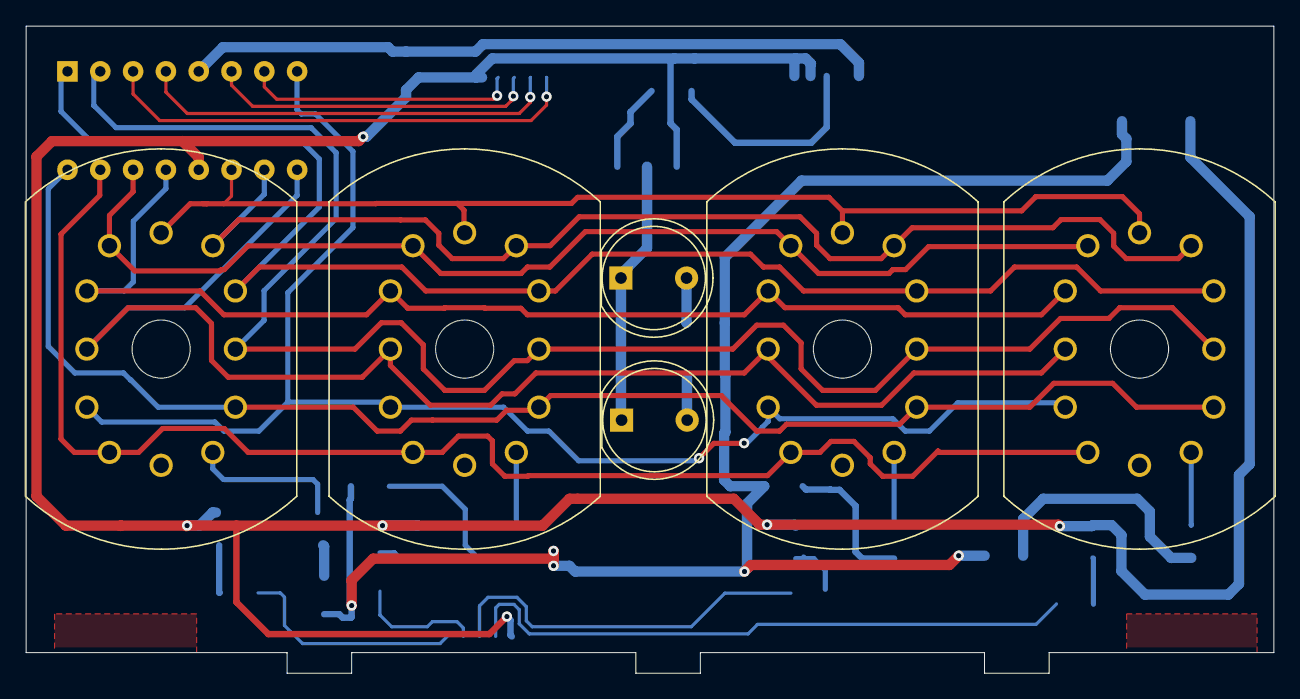
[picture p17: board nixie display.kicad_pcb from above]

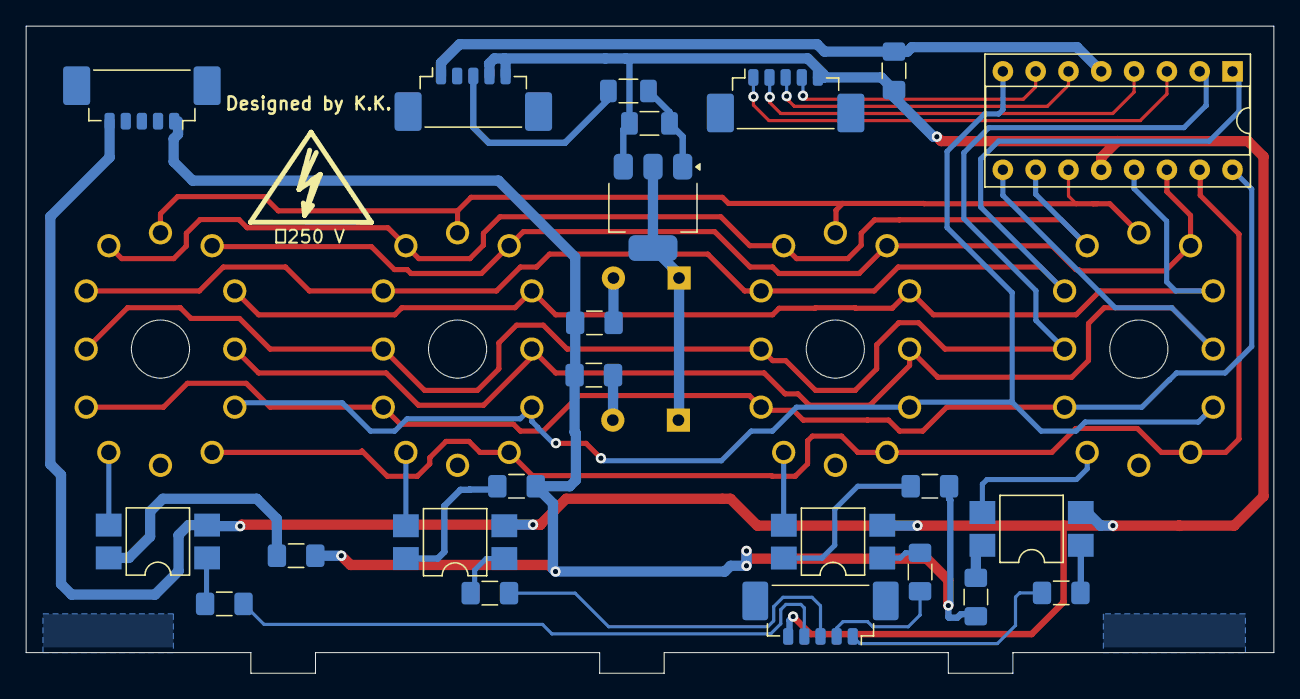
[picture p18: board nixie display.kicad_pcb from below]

Board: 2 copper layers, 96.6 x 50.1 mm, 30 parts (24 on the bottom side), 38 nets.

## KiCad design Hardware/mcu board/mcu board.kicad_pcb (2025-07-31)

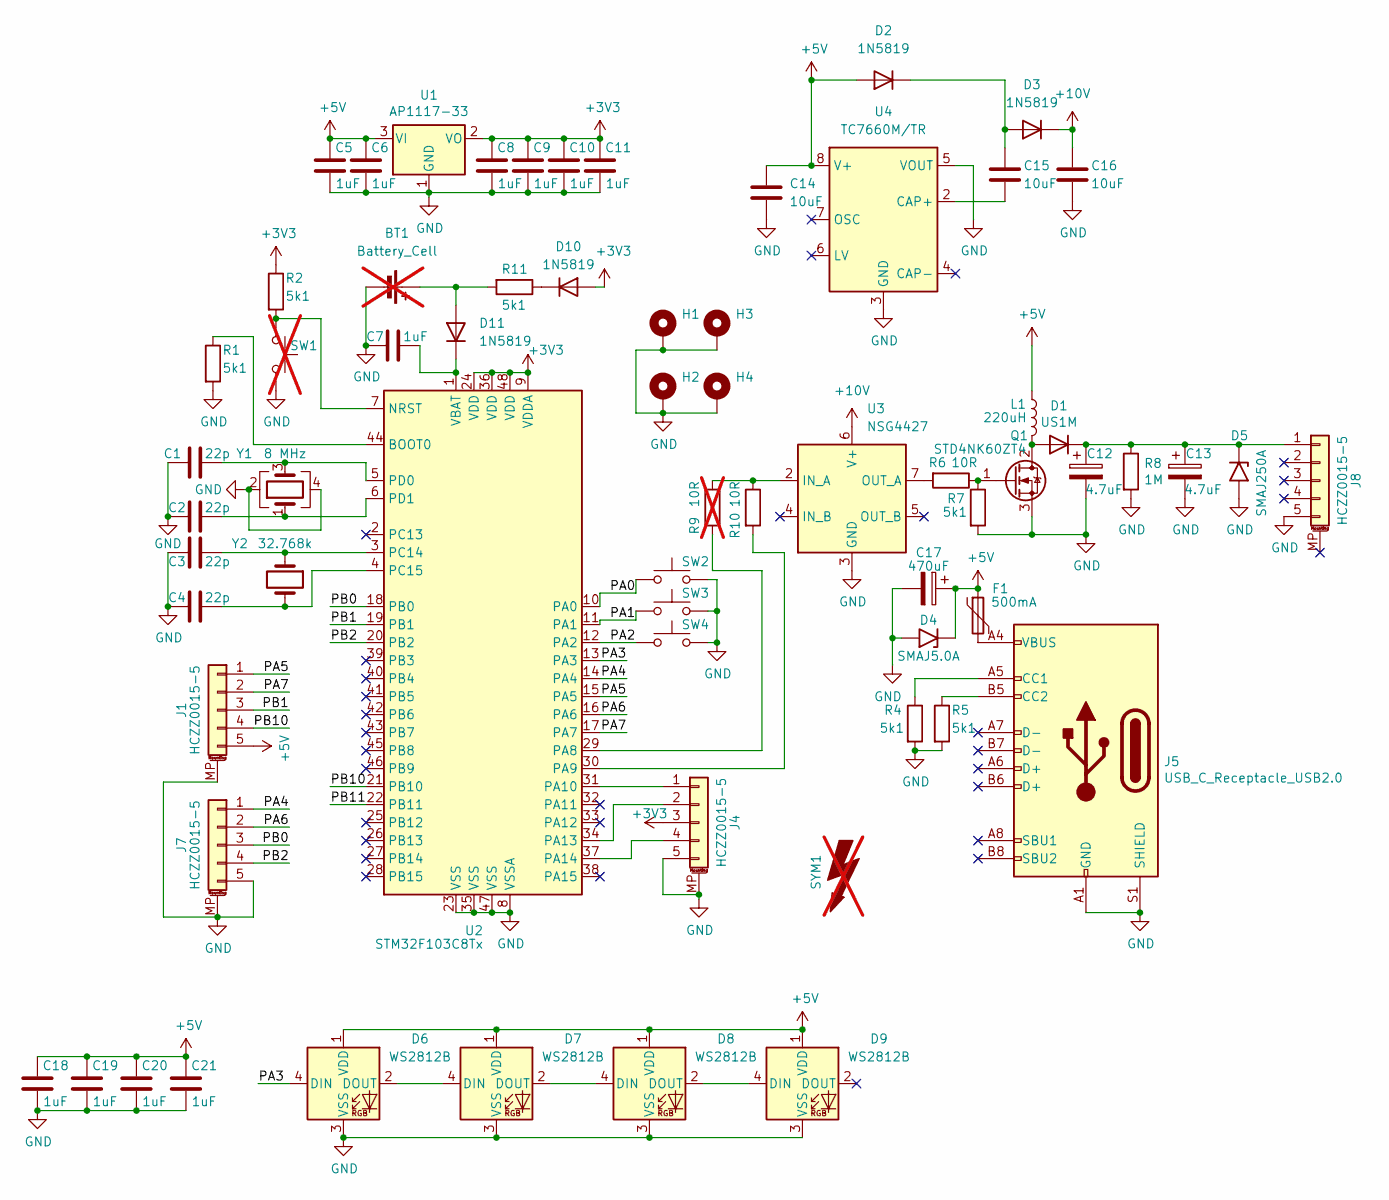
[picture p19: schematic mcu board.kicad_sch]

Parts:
BT1: Battery_Cell; BatteryHolder_Seiko_MS621F; not fitted
C1, C2, C3, C4: 22p; C_0402_1005Metric_Pad0.74x0.62mm_HandSolder; Part Number CC0402JRNPO9BN180
C5, C6, C7, C8, C9, C10, C11, C18, C19, C20, C21: CGA0603X5R105K160JT; C_0603_1608Metric_Pad1.08x0.95mm_HandSolder; Part Number CC0603KRX5R8BB105
C12, C13: 189RV165; CP_Elec_8x10; Part Number 189RV165
C14, C15, C16: 10uF; C_1206_3216Metric_Pad1.33x1.80mm_HandSolder; Part Number CC1206KKX5R8BB106
C17: GVE1C477M0810CNVC; CP_Elec_8x10; Part Number GVE1C477M0810CNVC
D1: US1M; D_SMA; Part Number US1M
D2, D3, D10, D11: 1N5819; D_SOD-123; Part Number 1N5819HW-7-F
D4: SMAJ5.0A; D_SMA; Part Number SMAJ5.0A
D5: SMAJ250A; D_SMA; Part Number SMAJ250A
D6, D7, D8, D9: WS2812B; LED_WS2812B_PLCC4_5.0x5.0mm_P3.2mm; Part Number XL-5050RGBC-WS2812B
F1: JK-MSMD050-30; Fuse_1812_4532Metric_Pad1.30x3.40mm_HandSolder; Part Number JK-MSMD050-30
H1, H2, H3, H4: SMTSO3080MTJ; Mounting_Wuerth_WA-SMSI-M3_H8mm_9774080360; Part Number SMTSO3080MTJ
J1, J4, J7, J8: HCZZ0015-5; Molex_PicoBlade_53398-0571_1x05-1MP_P1.25mm_Vertical; Part Number HCZZ0015-5
J5: USB_C_Receptacle_USB2.0; USB_C_Receptacle_Palconn_UTC16-G; Part Number TYPE-C-31-M-12
L1: CYH127-220UH; L_Wuerth_WE-PD-Typ-LS_Handsoldering; Part Number SHOU HAN CYH125-330UH
Q1: STD4NK60ZT4; TO-252-2; Part Number STD4NK60ZT4
R1, R2, R4, R5, R7, R11: 5k1; R_0402_1005Metric_Pad0.72x0.64mm_HandSolder; Part Number RC0402FR-075K1L
R6, R10: 10R; R_0402_1005Metric_Pad0.72x0.64mm_HandSolder; Part Number RC0402FR-0710RL
R8: 1M; R_1206_3216Metric_Pad1.30x1.75mm_HandSolder; Part Number RC1206FR-071ML
R9: 10R; R_0402_1005Metric_Pad0.72x0.64mm_HandSolder; not fitted
SW1: TS-1101-C-W; SW_SPST_CK_RS282G05A3; not fitted
SW2, SW3, SW4: XKB5858-W-F-75; Part Number XKB5858-W-F-75
SYM1: SYM_Flash_Large; HighVoltage; not fitted
U1: AP1117-33; SOT-223-3_TabPin2; Part Number AMS1117-3.3
U2: STM32F103C8Tx; LQFP-48_7x7mm_P0.5mm; Part Number STM32F103C8T6
U3: NSG4427; SOIC-8_3.9x4.9mm_P1.27mm; Part Number NSG4427
U4: TC7660M/TR; SOIC-8_3.9x4.9mm_P1.27mm; Part Number TC7660M/TR
Y1: TAXM8M4RFDCET2T; Crystal_SMD_3225-4Pin_3.2x2.5mm; Part Number TAXM8M4RFDCET2T
Y2: XKXGI-SUA-32.768K; Crystal_SMD_G8-2Pin_3.2x1.5mm_HandSoldering; Part Number XKXGI-SUA-32.768K

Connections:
+3V3: C8.2, C9.2, C10.2, C11.2, D10.2 (A), J4.3, R2.1, U1.2 (VO), U2.9 (VDDA), U2.24 (VDD), U2.36 (VDD), U2.48 (VDD)
+5V: C5.2, C6.2, C14.1, C17.1, C18.2, C19.2, C20.2, C21.2, D2.2 (A), D4.1 (A1), D6.1 (VDD), D7.1 (VDD), D8.1 (VDD), D9.1 (VDD), F1.1, J1.5, L1.1, U1.3 (VI), U4.8 (V+)
+10V: C16.1, D3.1 (K), U3.6 (V+)
/PA0: SW2.1, U2.10 (PA0)
/PA1: SW3.1, U2.11 (PA1)
/PA2: SW4.1, U2.12 (PA2)
/PA3: D6.4 (DIN), U2.13 (PA3)
/PA4: J7.1, U2.14 (PA4)
/PA5: J1.1, U2.15 (PA5)
/PA6: J7.2, U2.16 (PA6)
/PA7: J1.2, U2.17 (PA7)
/PB0: J7.3, U2.18 (PB0)
/PB1: J1.3, U2.19 (PB1)
/PB2: J7.4, U2.20 (PB2)
/PB10: J1.4, U2.21 (PB10)
/PB11: U2.22 (PB11)
GND: BT1.2 (-), C1.2, C2.2, C3.2, C4.2, C5.1, C6.1, C7.1, C8.1, C9.1, C10.1, C11.1, C12.2, C13.2, C14.2, C16.2, C17.2, C18.1, C19.1, C20.1, C21.1, D4.2 (A2), D5.2 (A2), D6.3 (VSS), D7.3 (VSS), D8.3 (VSS), D9.3 (VSS), H1.1, H2.1, H3.1, H4.1, J1.MP (MountPin), J4.5, J4.MP (MountPin), J5.A1 (GND), J5.A12 (GND), J5.B1 (GND), J5.B12 (GND), J5.S1 (SHIELD), J7.5, J7.MP (MountPin), J8.5, Q1.3 (S), R1.2, R4.2, R5.2, R7.2, R8.2, SW1.2, SW2.2, SW3.2, SW4.2, U1.1 (GND), U2.8 (VSSA), U2.23 (VSS), U2.35 (VSS), U2.47 (VSS), U3.3 (GND), U4.3 (GND), U4.5 (VOUT), Y1.2, Y1.4
unnamed: BT1.1 (+), D11.2 (A), R11.2
unnamed: D1.2 (A), L1.2, Q1.2 (D)
unnamed: C12.1, C13.1, D1.1 (K), D5.1 (A1), J8.1, R8.1
unnamed: C15.1, D2.1 (K), D3.2 (A)
unnamed: D6.2 (DOUT), D7.4 (DIN)
unnamed: D7.2 (DOUT), D8.4 (DIN)
unnamed: D8.2 (DOUT), D9.4 (DIN)
unnamed: D10.1 (K), R11.1
unnamed: C7.2, D11.1 (K), U2.1 (VBAT)
unnamed: F1.2, J5.A4 (VBUS), J5.A9 (VBUS), J5.B4 (VBUS), J5.B9 (VBUS)
unnamed: J4.1, U2.31 (PA10)
unnamed: J4.2, U2.34 (PA13)
unnamed: J4.4, U2.37 (PA14)
unnamed: J5.A5 (CC1), R4.1
unnamed: J5.B5 (CC2), R5.1
unnamed: Q1.1 (G), R6.1, R7.1
unnamed: R1.1, U2.44 (BOOT0)
unnamed: R2.2, SW1.1, U2.7 (NRST)
unnamed: R9.2, U2.29 (PA8)
unnamed: R10.2, U2.30 (PA9)
unnamed: C3.1, U2.3 (PC14), Y2.1
unnamed: C4.1, U2.4 (PC15), Y2.2
unnamed: C1.1, U2.5 (PD0), Y1.3
unnamed: C2.1, U2.6 (PD1), Y1.1
unnamed: R9.1, R10.1, U3.2 (IN_A)
unnamed: R6.2, U3.7 (OUT_A)
unnamed: C15.2, U4.2 (CAP+)

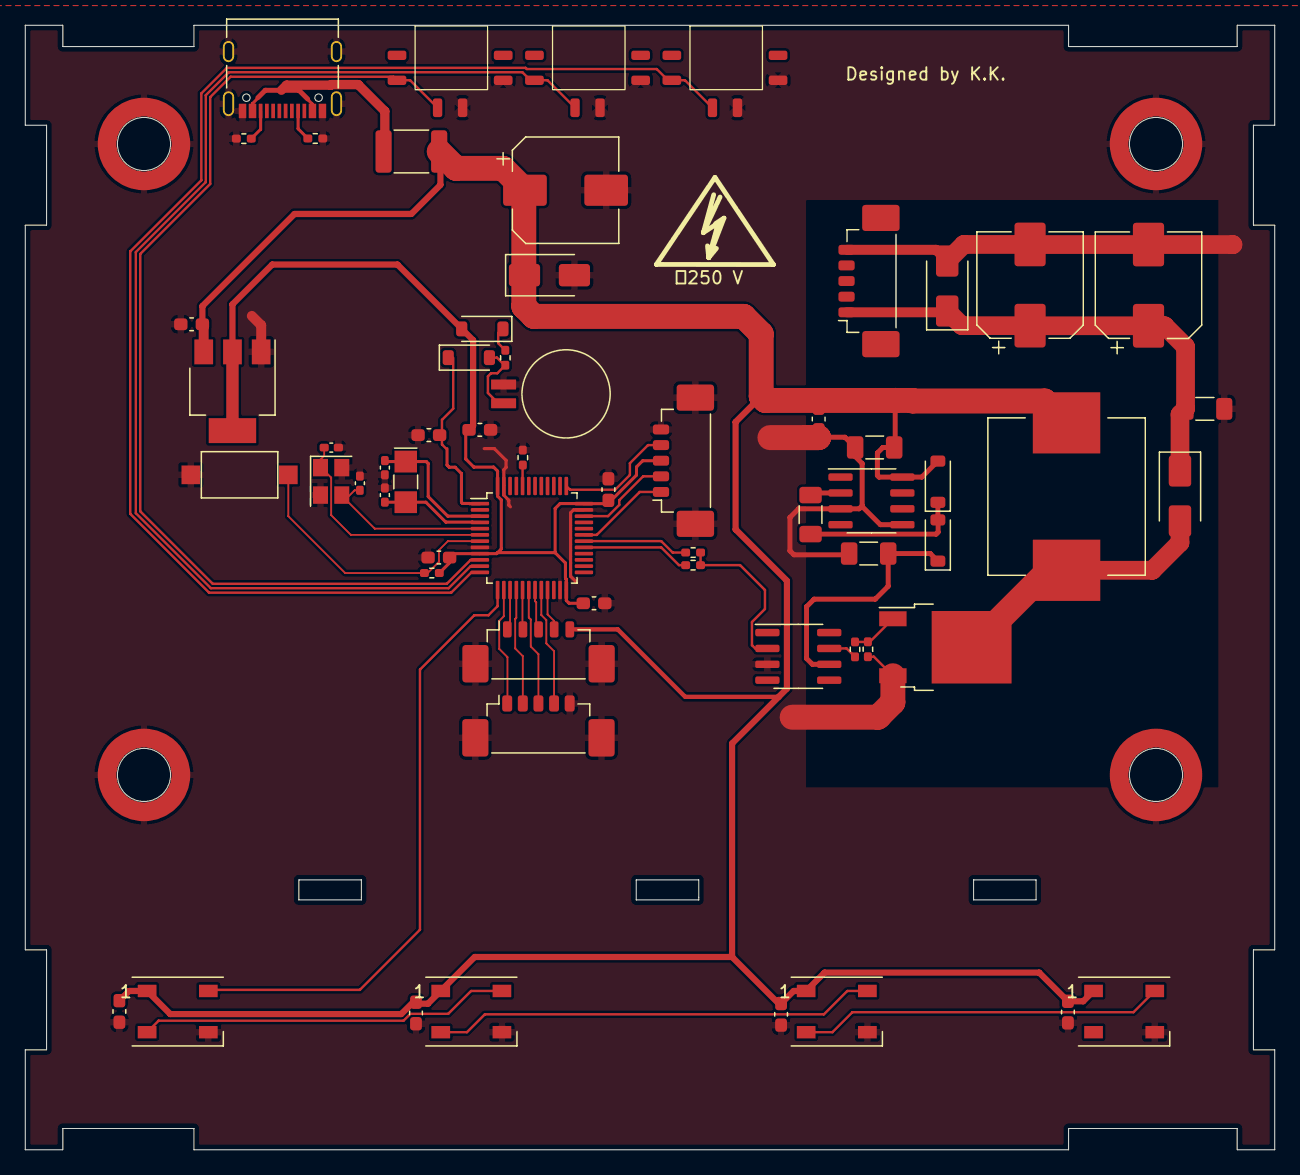
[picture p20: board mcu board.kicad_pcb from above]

Board: 2 copper layers, 100.0 x 90.0 mm, 66 parts (0 on the bottom side), 43 nets.

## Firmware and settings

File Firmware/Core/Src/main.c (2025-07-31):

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
/* Includes ------------------------------------------------------------------*/
#include "main.h"

/* USER CODE BEGIN Includes */
#include <stdbool.h>
#include <stdlib.h>
// #include "stm32f10x_flash.h"
/* USER CODE END Includes */

/* USER CODE BEGIN PD */

#define GPIO_SET_PIN(port, pin) ((port)->BSRR = (pin))
#define GPIO_CLEAR_PIN(port, pin) ((port)->BSRR = (pin << 16u))

#define DUTY 195
// #define DUTY 0

// these timings shoud be randomised a bit, to avoid stroboscopic effect when
// filming
#define DELAY1 469  // smth about 500
#define DELAY2 2047 // smth about 2000

#define TEST_FUNC_DELAY 10

#define DEC_BIT0 GPIOA, GPIO_PIN_5
#define DEC_BIT1 GPIOB, GPIO_PIN_1
#define DEC_BIT2 GPIOB, GPIO_PIN_10
#define DEC_BIT3 GPIOA, GPIO_PIN_7

#define RGB_NUM 4
#define PWM_MIN 0
#define PWM_HIGH 7
#define PWM_LOW 2
#define RGB_OFFSET 100

#define NEON_ORANGE 0xFF6700
#define RED 0xFF0000
#define GREEN 0x00FF00
#define BLUE 0x0000FF
#define ROYAL_FUCHSIA 0xCA2C92
#define POMEGRANATE 0xF34723
#define MINT 0x3EB489
#define CORNFLOWER_BLUE 0x6495ED
#define BULGARIAN_ROSE 0x480607
#define BYZANTINE 0xBD33A4
#define AMBER 0xFFBF00
#define PERSIAN_INDIGO 0x32127A
#define BLACK 0x000000

#define NEON_ORANGE_BLINK 14
#define RANDOM_BLINK 15
#define NUMBER_OF_COLORS 12 // except black which is a zero element of array
/* USER CODE END PD */

RTC_HandleTypeDef hrtc;

TIM_HandleTypeDef htim1;
TIM_HandleTypeDef htim3;

/* USER CODE BEGIN PV */
_Bool irq_flag = 0;

uint8_t a, b, c, d; // digits
_Bool sp; // flag that ensures that test() func will be called single time
          // during a minute if the conditions for calling test() are met
uint16_t i; // tick counter in while(1) to set button press delay
extern volatile uint8_t num; // anode state machine variable in while(1)
uint32_t get_tick_prev =
    0; // prev timestamp state variable for nonblocking wait in while(1) loop
       // for working with "+" and "-" buttons
uint32_t get_tick_prev_btn3 =
    0; // prev timestamp state variable for nonblocking wait in while(1) loop
       // for working with "RGB" button
uint32_t _test_tick_prev =
    0; // prev timestamp state variable for nonblocking wait in test() func
uint32_t tmp_minutes = 0; // the whole day's tmp minutes counter for correct
                          // work of the time subtraction code in while(1)
volatile uint32_t tick_us = 0;
_Bool show_rgb_demo = true;
uint32_t rgb_demo_color = NEON_ORANGE;
uint8_t tmp_color_counter = 1;

typedef struct {
  uint32_t color;
  uint8_t top_point_delay_step;
  uint32_t get_tick_prev_us; // prev timestamp state variable for nonblocking
                             // wait in rgb_demo(...)
  uint8_t current_led_num;
  _Bool init;
} RGBDemoStateMachine;

RGBDemoStateMachine rgb_demo_state_machine;

uint8_t rgb_mode = 0;
uint32_t rgb_mode_colors[256] = {
    BLACK,          RED,           GREEN,
    BLUE,           ROYAL_FUCHSIA, NEON_ORANGE,
    POMEGRANATE,    MINT,          CORNFLOWER_BLUE,
    BULGARIAN_ROSE, BYZANTINE,     AMBER,
    PERSIAN_INDIGO,
};

uint16_t dma_pwm_buff[RGB_NUM * 24 + RGB_OFFSET] = {
    0,
};
uint32_t colors_buf[RGB_NUM] = {
    0,
};
uint32_t grb_colors_buf[RGB_NUM] = {
    0,
};
/* USER CODE END PV */

void SystemClock_Config(void);
static void MX_GPIO_Init(void);
static void MX_TIM1_Init(void);
static void MX_RTC_Init(void);
static void MX_TIM3_Init(void);
/* USER CODE BEGIN PFP */

volatile uint32_t my_random(uint32_t min, uint32_t max);
void decoder_write(uint8_t num);
__STATIC_INLINE uint32_t GetTick_us();
void all_clear();
__STATIC_INLINE void wait(__IO uint32_t us);
void anode_switch(uint8_t num);
void test();
void grb_to_pwm(uint32_t *grb_buf, uint16_t *out_buf);
__STATIC_INLINE void bitbang_rgb_write(uint16_t *in_buf, int len);
void rgb_to_grb(uint32_t *rgb_buf, uint32_t *grb_buf);
void rgb_demo(RGBDemoStateMachine *states, uint32_t in_color,
              uint32_t grayscale_num, uint32_t grayscale_shift,
              uint32_t step_delay);
void reset_rgb_demo_states(RGBDemoStateMachine *states);
void set_array_with_color(uint32_t *rgb_buf, uint32_t color);
void SetReadOutProtection();

/* USER CODE END PFP */

/**
 * @brief  The application entry point.
 * @retval int
 */
int main(void) {

  /* MCU Configuration--------------------------------------------------------*/

  /* Reset of all peripherals, Initializes the Flash interface and the Systick.
   */
  HAL_Init();

  /* Configure the system clock */
  SystemClock_Config();

  /* Initialize all configured peripherals */
  MX_GPIO_Init();
  MX_TIM1_Init();
  MX_RTC_Init();
  MX_TIM3_Init();
  /* USER CODE BEGIN 2 */
  HAL_TIM_PWM_Start(&htim1, TIM_CHANNEL_2);
  HAL_TIM_PWM_Start(&htim1, TIM_CHANNEL_3);
  HAL_TIM_PWM_Start_IT(&htim3, TIM_CHANNEL_1);
  HAL_RTCEx_TamperIRQHandler(&hrtc);
  for (int i = 0; i < DUTY; i++) {
    TIM1->CCR2 = i;
    HAL_Delay(10);
  }
  RTC_TimeTypeDef sTime;
  RTC_DateTypeDef sDate;
  HAL_RTC_SetDate(&hrtc, &sDate, RTC_FORMAT_BIN);
  test();
  rgb_to_grb(colors_buf, grb_colors_buf);
  grb_to_pwm(grb_colors_buf, dma_pwm_buff);
  rgb_mode = HAL_RTCEx_BKUPRead(&hrtc, RTC_BKP_DR1);

  SetReadOutProtection();

  // HAL_TIM_PWM_Start_DMA(&htim2, TIM_CHANNEL_4, (uint32_t*)dma_pwm_buff,
  // RGB_NUM*24+RGB_OFFSET);
  /* USER CODE END 2 */

  /* Infinite loop */
  /* USER CODE BEGIN WHILE */
  while (1) {
    if (rgb_mode == NEON_ORANGE_BLINK) {
      show_rgb_demo = true;
      rgb_demo_color = NEON_ORANGE;

    } else if (rgb_mode == RANDOM_BLINK) {
      show_rgb_demo = true;
    }
    if (show_rgb_demo) {
      rgb_demo(&rgb_demo_state_machine, rgb_demo_color, 100, 5, 10);
      if (!rgb_demo_state_machine.init &&
          rgb_demo_state_machine.current_led_num < 3) {
        rgb_demo_state_machine.current_led_num++;
        if (rgb_mode == RANDOM_BLINK) {
          if (tmp_color_counter < NUMBER_OF_COLORS + 1) {
            tmp_color_counter++;
          }
          if (tmp_color_counter >= NUMBER_OF_COLORS + 1) {
            tmp_color_counter = my_random(1, NUMBER_OF_COLORS);
          }
          rgb_demo_color = rgb_mode_colors[tmp_color_counter];
        }
      } else if (!rgb_demo_state_machine.init &&
                 rgb_demo_state_machine.current_led_num >= 3) {
        rgb_demo_state_machine.current_led_num = 0;
        show_rgb_demo = false;

        if (rgb_mode <= NUMBER_OF_COLORS) {
          set_array_with_color(colors_buf, rgb_mode_colors[rgb_mode]);
          rgb_to_grb(colors_buf, grb_colors_buf);
          grb_to_pwm(grb_colors_buf, dma_pwm_buff);
          bitbang_rgb_write(dma_pwm_buff, RGB_NUM * 24 + RGB_OFFSET);
        }
      }
    }

    // bitbang_rgb_write(dma_pwm_buff, RGB_NUM*24+RGB_OFFSET);
    HAL_RTC_GetTime(&hrtc, &sTime, RTC_FORMAT_BIN);
    d = sTime.Hours / 10;
    c = sTime.Hours % 10;
    b = sTime.Minutes / 10;
    a = sTime.Minutes % 10;
    if (irq_flag == 1) {
      anode_switch(num);
      irq_flag = 0;
    }

    if (HAL_GPIO_ReadPin(GPIOA, GPIO_PIN_0) == 0) {
      if (i < 5) {
        if ((HAL_GetTick() - get_tick_prev) > 250) {
          sTime.Minutes++;
          HAL_RTC_SetTime(&hrtc, &sTime, RTC_FORMAT_BIN);
          HAL_RTC_SetDate(&hrtc, &sDate, RTC_FORMAT_BIN);
          get_tick_prev = HAL_GetTick();
          i++;
        }
      } else {
        if ((HAL_GetTick() - get_tick_prev) > 20) {
          sTime.Minutes++;
          HAL_RTC_SetTime(&hrtc, &sTime, RTC_FORMAT_BIN);
          HAL_RTC_SetDate(&hrtc, &sDate, RTC_FORMAT_BIN);
          get_tick_prev = HAL_GetTick();
          i++;
        }
      }
    } else if (HAL_GPIO_ReadPin(GPIOA, GPIO_PIN_1) == 0) {
      if (i < 5) {
        if ((HAL_GetTick() - get_tick_prev) > 250) {
          tmp_minutes--;
          if (tmp_minutes > 1439) {
            tmp_minutes = 1439;
          }
          sTime.Hours = tmp_minutes / 60;
          sTime.Minutes = tmp_minutes % 60;
          HAL_RTC_SetTime(&hrtc, &sTime, RTC_FORMAT_BIN);
          HAL_RTC_SetDate(&hrtc, &sDate, RTC_FORMAT_BIN);
          get_tick_prev = HAL_GetTick();
          i++;
        }
      } else {
        if ((HAL_GetTick() - get_tick_prev) > 20) {
          tmp_minutes--;
          if (tmp_minutes > 1439) {
            tmp_minutes = 1439;
          }
          sTime.Hours = tmp_minutes / 60;
          sTime.Minutes = tmp_minutes % 60;
          HAL_RTC_SetTime(&hrtc, &sTime, RTC_FORMAT_BIN);
          HAL_RTC_SetDate(&hrtc, &sDate, RTC_FORMAT_BIN);
          get_tick_prev = HAL_GetTick();
          i++;
        }
      }
    } else {
      i = 0;
      tmp_minutes = sTime.Minutes + sTime.Hours * 60;
    }

    if (HAL_GPIO_ReadPin(GPIOA, GPIO_PIN_2) == 0) {
      if ((HAL_GetTick() - get_tick_prev_btn3) > 300) {
        rgb_mode++;
        if (rgb_mode > RANDOM_BLINK) {
          rgb_mode = 0;
          show_rgb_demo = false;
          reset_rgb_demo_states(&rgb_demo_state_machine);
          set_array_with_color(colors_buf, BLACK);
        }
        if (rgb_mode <= NUMBER_OF_COLORS) {
          set_array_with_color(colors_buf, rgb_mode_colors[rgb_mode]);
        } else if (rgb_mode == NUMBER_OF_COLORS + 1) { // special multicolor
                                                       // mode
          colors_buf[0] = CORNFLOWER_BLUE;
          colors_buf[1] = NEON_ORANGE;
          colors_buf[2] = MINT;
          colors_buf[3] = BYZANTINE;
        } else if (rgb_mode > NUMBER_OF_COLORS + 1 &&
                   rgb_mode <= NEON_ORANGE_BLINK) {
          reset_rgb_demo_states(&rgb_demo_state_machine);
          set_array_with_color(colors_buf, BLACK);
        }
        HAL_PWR_EnableBkUpAccess();
        HAL_RTCEx_BKUPWrite(&hrtc, RTC_BKP_DR1, rgb_mode);
        // HAL_PWR_DisableBkUpAccess();
        rgb_to_grb(colors_buf, grb_colors_buf);
        grb_to_pwm(grb_colors_buf, dma_pwm_buff);
        bitbang_rgb_write(dma_pwm_buff, RGB_NUM * 24 + RGB_OFFSET);
        get_tick_prev_btn3 = HAL_GetTick();
      }
    }

    if ((sTime.Minutes % 10 == 5) && (sp == 0) &&
        (HAL_GPIO_ReadPin(GPIOA, GPIO_PIN_1)) &&
        (HAL_GPIO_ReadPin(GPIOA, GPIO_PIN_0))) {
      test();
      sp = 1;
    }
    if (sTime.Minutes % 10 != 5) {
      sp = 0;
    }
    /* USER CODE END WHILE */

    /* USER CODE BEGIN 3 */
  }
  /* USER CODE END 3 */
}

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
/* USER CODE BEGIN 4 */

volatile uint32_t my_random(uint32_t min, uint32_t max) {
  srand(tick_us);
  return min + (uint32_t)rand() / (RAND_MAX / (max - min + 1) + 1);
}

void decoder_write(uint8_t num) {
  switch (num) {
  case 0:
    HAL_GPIO_WritePin(DEC_BIT0, GPIO_PIN_RESET);
    HAL_GPIO_WritePin(DEC_BIT1, GPIO_PIN_RESET);
    HAL_GPIO_WritePin(DEC_BIT2, GPIO_PIN_RESET);
    HAL_GPIO_WritePin(DEC_BIT3, GPIO_PIN_RESET);
    break;
  case 1:
    HAL_GPIO_WritePin(DEC_BIT0, GPIO_PIN_SET);
    HAL_GPIO_WritePin(DEC_BIT1, GPIO_PIN_RESET);
    HAL_GPIO_WritePin(DEC_BIT2, GPIO_PIN_RESET);
    HAL_GPIO_WritePin(DEC_BIT3, GPIO_PIN_RESET);
    break;
  case 2:
    HAL_GPIO_WritePin(DEC_BIT0, GPIO_PIN_RESET);
    HAL_GPIO_WritePin(DEC_BIT1, GPIO_PIN_SET);
    HAL_GPIO_WritePin(DEC_BIT2, GPIO_PIN_RESET);
    HAL_GPIO_WritePin(DEC_BIT3, GPIO_PIN_RESET);
    break;
  case 3:
    HAL_GPIO_WritePin(DEC_BIT0, GPIO_PIN_SET);
    HAL_GPIO_WritePin(DEC_BIT1, GPIO_PIN_SET);
    HAL_GPIO_WritePin(DEC_BIT2, GPIO_PIN_RESET);
    HAL_GPIO_WritePin(DEC_BIT3, GPIO_PIN_RESET);
    break;
  case 4:
    HAL_GPIO_WritePin(DEC_BIT0, GPIO_PIN_RESET);
    HAL_GPIO_WritePin(DEC_BIT1, GPIO_PIN_RESET);
    HAL_GPIO_WritePin(DEC_BIT2, GPIO_PIN_SET);
    HAL_GPIO_WritePin(DEC_BIT3, GPIO_PIN_RESET);
    break;
  case 5:
    HAL_GPIO_WritePin(DEC_BIT0, GPIO_PIN_SET);
    HAL_GPIO_WritePin(DEC_BIT1, GPIO_PIN_RESET);
    HAL_GPIO_WritePin(DEC_BIT2, GPIO_PIN_SET);
    HAL_GPIO_WritePin(DEC_BIT3, GPIO_PIN_RESET);
    break;
  case 6:
    HAL_GPIO_WritePin(DEC_BIT0, GPIO_PIN_RESET);
    HAL_GPIO_WritePin(DEC_BIT1, GPIO_PIN_SET);
    HAL_GPIO_WritePin(DEC_BIT2, GPIO_PIN_SET);
    HAL_GPIO_WritePin(DEC_BIT3, GPIO_PIN_RESET);
    break;
  case 7:
    HAL_GPIO_WritePin(DEC_BIT0, GPIO_PIN_SET);
    HAL_GPIO_WritePin(DEC_BIT1, GPIO_PIN_SET);
    HAL_GPIO_WritePin(DEC_BIT2, GPIO_PIN_SET);
    HAL_GPIO_WritePin(DEC_BIT3, GPIO_PIN_RESET);
    break;
  case 8:
    HAL_GPIO_WritePin(DEC_BIT0, GPIO_PIN_RESET);
    HAL_GPIO_WritePin(DEC_BIT1, GPIO_PIN_RESET);
    HAL_GPIO_WritePin(DEC_BIT2, GPIO_PIN_RESET);
    HAL_GPIO_WritePin(DEC_BIT3, GPIO_PIN_SET);
    break;
  case 9:
    HAL_GPIO_WritePin(DEC_BIT0, GPIO_PIN_SET);
    HAL_GPIO_WritePin(DEC_BIT1, GPIO_PIN_RESET);
    HAL_GPIO_WritePin(DEC_BIT2, GPIO_PIN_RESET);
    HAL_GPIO_WritePin(DEC_BIT3, GPIO_PIN_SET);
    break;
  }
}

__STATIC_INLINE uint32_t GetTick_us() { return tick_us; }

void all_clear() {
  HAL_GPIO_WritePin(GPIOB, GPIO_PIN_1 | GPIO_PIN_10, GPIO_PIN_RESET);
  HAL_GPIO_WritePin(GPIOA, GPIO_PIN_10 | GPIO_PIN_7, GPIO_PIN_RESET);
}

__STATIC_INLINE void wait(__IO uint32_t us) {
  us *= (SystemCoreClock / 1000000) / 5;
  while (us--)
    ;
}

void anode_switch(uint8_t num) {
  switch (num) {
  case 0:
    HAL_GPIO_WritePin(GPIOB, GPIO_PIN_2, GPIO_PIN_RESET);
    wait(DELAY1);
    all_clear();
    decoder_write(d);
    HAL_GPIO_WritePin(GPIOA, GPIO_PIN_4, GPIO_PIN_SET);
    wait(DELAY2);
    break;
  case 1:
    // HAL_GPIO_WritePin(GPIOA, GPIO_PIN_4, GPIO_PIN_RESET);
    break;
  case 2:
    HAL_GPIO_WritePin(GPIOA, GPIO_PIN_4, GPIO_PIN_RESET);
    wait(DELAY1);
    all_clear();
    decoder_write(c);
    HAL_GPIO_WritePin(GPIOA, GPIO_PIN_6, GPIO_PIN_SET);
    wait(DELAY2);
    break;
  case 3:
    // HAL_GPIO_WritePin(GPIOA, GPIO_PIN_6, GPIO_PIN_RESET);
    break;
  case 4:
    HAL_GPIO_WritePin(GPIOA, GPIO_PIN_6, GPIO_PIN_RESET);
    wait(DELAY1);
    all_clear();
    decoder_write(b);
    HAL_GPIO_WritePin(GPIOB, GPIO_PIN_0, GPIO_PIN_SET);
    wait(DELAY2);
    break;
  case 5:
    // HAL_GPIO_WritePin(GPIOB, GPIO_PIN_0, GPIO_PIN_RESET);
    break;
  case 6:
    HAL_GPIO_WritePin(GPIOB, GPIO_PIN_0, GPIO_PIN_RESET);
    wait(DELAY1);
    all_clear();
    decoder_write(a);
    HAL_GPIO_WritePin(GPIOB, GPIO_PIN_2, GPIO_PIN_SET);
    wait(DELAY2);
    break;
  case 7:
    // HAL_GPIO_WritePin(GPIOB, GPIO_PIN_2, GPIO_PIN_RESET);
    break;
  }
}

void test() {
  uint32_t tmp_counter = 0;
  uint32_t tmp_value = 0;
  while (tmp_counter <= 15) {
    if ((HAL_GetTick() - _test_tick_prev) > TEST_FUNC_DELAY) {
      _test_tick_prev = GetTick_us();
      tmp_counter++;
      tmp_value = my_random(0, 9999);
    }

    a = tmp_value / 1000;
    b = (tmp_value / 100) % 10;
    c = (tmp_value / 10) % 10;
    d = tmp_value % 10;

    for (int i = 0; i < 8; i++) {
      anode_switch(i);
      wait(DELAY2);
    }
  }
}

void grb_to_pwm(uint32_t *grb_buf, uint16_t *out_buf) {
  for (int i = 0; i < RGB_NUM * 24 + RGB_OFFSET; i++) {
    if (i < (RGB_OFFSET / 2)) {
      out_buf[i] = PWM_MIN;
    } else if (i >= (RGB_OFFSET / 2) && i < RGB_NUM * 24 + (RGB_OFFSET / 2)) {
      _Bool current_bit = (grb_buf[((i - (RGB_OFFSET / 2)) / 24)] >>
                           (23 - ((i - (RGB_OFFSET / 2)) % 24))) %
                          2;
      if (current_bit) {
        out_buf[i] = PWM_HIGH;
      } else {
        out_buf[i] = PWM_LOW;
      }
    } else {
      out_buf[i] = PWM_MIN;
    }
  }
}

__STATIC_INLINE void bitbang_rgb_write(uint16_t *in_buf, int len) {
  __disable_irq();
  for (int i = 0; i < len; i++) {
    if (in_buf[i] == PWM_LOW) {
      GPIO_SET_PIN(GPIOA, GPIO_PIN_3);
      __NOP();
      __NOP();
      __NOP();
      __NOP();
      __NOP();
      __NOP();
      __NOP();
      __NOP();
      __NOP();
      __NOP();
      __NOP();
      __NOP();
      __NOP();
      GPIO_CLEAR_PIN(GPIOA, GPIO_PIN_3);
      __NOP();
      __NOP();
      __NOP();
      __NOP();
      __NOP();
      __NOP();
      __NOP();
      __NOP();
      __NOP();
      __NOP();
      __NOP();
      __NOP();
      __NOP();
      __NOP();
      __NOP();
      __NOP();
      __NOP();
      __NOP();
      __NOP();
      __NOP();
      __NOP();
      __NOP();
      __NOP();
      __NOP();
      __NOP();
      __NOP();
      __NOP();
      __NOP();
      __NOP();
      __NOP();
      __NOP();
      __NOP();
      __NOP();
      __NOP();
      __NOP();
      __NOP();
      __NOP();
      __NOP();
      __NOP();
      __NOP();
    } else if (in_buf[i] == PWM_HIGH) {
      GPIO_SET_PIN(GPIOA, GPIO_PIN_3);
      __NOP();
      __NOP();
      __NOP();
      __NOP();
      __NOP();
      __NOP();
      __NOP();
      __NOP();
      __NOP();
      __NOP();
      __NOP();
      __NOP();
      __NOP();
      __NOP();
      __NOP();
      __NOP();
      __NOP();
      __NOP();
      __NOP();
      __NOP();
      __NOP();
      __NOP();
      __NOP();
      __NOP();
      __NOP();
      __NOP();
      __NOP();
      __NOP();
      __NOP();
      __NOP();
      __NOP();
      __NOP();
      __NOP();
      __NOP();
      __NOP();
      __NOP();
      __NOP();
      __NOP();
      __NOP();
      __NOP();
      GPIO_CLEAR_PIN(GPIOA, GPIO_PIN_3);
      __NOP();
      __NOP();
      __NOP();
      __NOP();
      __NOP();
      __NOP();
      __NOP();
      __NOP();
      __NOP();
      __NOP();
      __NOP();
      __NOP();
      __NOP();
    } else {
      GPIO_CLEAR_PIN(GPIOA, GPIO_PIN_3);
    }
  }
  __enable_irq();
}

void rgb_to_grb(uint32_t *rgb_buf, uint32_t *grb_buf) {
  for (int i = 0; i < RGB_NUM; i++) {
    grb_buf[i] = ((rgb_buf[i] & 0x00FF00) << 8) +
                 ((rgb_buf[i] & 0xFF0000) >> 8) + (rgb_buf[i] & 0x0000FF);
  }
}

void rgb_demo(RGBDemoStateMachine *states, uint32_t in_color,
              uint32_t grayscale_num, uint32_t grayscale_shift,
              uint32_t step_delay) {
  float tmp_r = (float)((in_color & 0xFF0000) >> 16);
  float tmp_g = (float)((in_color & 0x00FF00) >> 8);
  float tmp_b = (float)((in_color & 0x0000FF));
  if (!states->init) {
    states->color = grayscale_shift;
    states->top_point_delay_step = 0;
    states->init = true;
  }
  if ((GetTick_us() - states->get_tick_prev_us) > step_delay) {
    if (states->color < grayscale_num && states->top_point_delay_step == 0) {
      states->color++;
    } else if (states->color == grayscale_num &&
               states->top_point_delay_step < 4) {
      states->top_point_delay_step++;
    } else if (states->top_point_delay_step == 4 &&
               states->color > grayscale_shift) {
      states->color--;
    } else if (states->top_point_delay_step == 4 &&
               states->color == grayscale_shift) {
      states->init = false;
    }
  }
  uint32_t tmp_color_buf[RGB_NUM] = {
      0,
  };
  if (states->current_led_num < 4) {
    tmp_color_buf[states->current_led_num] =
        ((uint32_t)(tmp_r /
                    ((float)(grayscale_num) - (float)(states->color + 1)))
         << 16) +
        ((uint32_t)(tmp_g /
                    ((float)(grayscale_num) - (float)(states->color + 1)))
         << 8) +
        ((uint32_t)(tmp_b /
                    ((float)(grayscale_num) - (float)(states->color + 1))));
  }
  rgb_to_grb(tmp_color_buf, grb_colors_buf);
  grb_to_pwm(grb_colors_buf, dma_pwm_buff);
  bitbang_rgb_write(dma_pwm_buff, RGB_NUM * 24 + RGB_OFFSET);

  states->get_tick_prev_us = GetTick_us();
}

void reset_rgb_demo_states(RGBDemoStateMachine *states) {
  states->color = 0;
  states->top_point_delay_step = 0;
  states->get_tick_prev_us = 0;
  states->current_led_num = 0;
  states->init = false;
}

void set_array_with_color(uint32_t *rgb_buf, uint32_t color) {
  for (int i = 0; i < RGB_NUM; i++) {
    rgb_buf[i] = color;
  }
}

void SetReadOutProtection() {
  FLASH_OBProgramInitTypeDef Optbyte;

  __disable_irq();
  HAL_FLASHEx_OBGetConfig(&Optbyte);        // read out RDPLvL
  if (Optbyte.RDPLevel == OB_RDP_LEVEL_0) { //
    Optbyte.OptionType = OPTIONBYTE_RDP;    // select RDP optionbyte
    Optbyte.RDPLevel = OB_RDP_LEVEL_1;      // select RDP level 1
    HAL_FLASH_Unlock();                     // unlock Flash
    HAL_FLASH_OB_Unlock();                  // unlock Optionbytes
    HAL_FLASHEx_OBProgram(&Optbyte);        // set RDP=1
    HAL_FLASH_OB_Launch();                  // write OB to Flash and reset
    HAL_FLASH_OB_Lock();                    // Lock Optionbytes
    HAL_FLASH_Lock();                       // lock Flash
  }
  __enable_irq();
}

/* USER CODE END 4 */
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


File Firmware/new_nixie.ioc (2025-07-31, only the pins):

Mcu.UserName=STM32F103C8Tx
PA0-WKUP.Signal=GPIO_Input
PA1.Signal=GPIO_Input
PA10.Signal=S_TIM1_CH3
PA13.Signal=SYS_JTMS-SWDIO
PA14.Signal=SYS_JTCK-SWCLK
PA2.Signal=GPIO_Input
PA3.Signal=GPIO_Output
PA4.Signal=GPIO_Output
PA5.Signal=GPIO_Output
PA6.Signal=GPIO_Output
PA7.Signal=GPIO_Output
PA9.Signal=S_TIM1_CH2
PB0.Signal=GPIO_Output
PB1.Signal=GPIO_Output
PB10.Signal=GPIO_Output
PB2.Signal=GPIO_Output
PC14-OSC32_IN.Signal=RCC_OSC32_IN
PC15-OSC32_OUT.Signal=RCC_OSC32_OUT
PD0-OSC_IN.Signal=RCC_OSC_IN
PD1-OSC_OUT.Signal=RCC_OSC_OUT

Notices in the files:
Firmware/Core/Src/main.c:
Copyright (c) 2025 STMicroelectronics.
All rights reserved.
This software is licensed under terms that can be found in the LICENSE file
